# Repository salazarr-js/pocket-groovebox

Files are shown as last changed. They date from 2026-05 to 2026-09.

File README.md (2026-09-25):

# Pocket Groovebox

🎹 A modern DIY pocket groovebox. Just for fun.



## Status

Hardware checkpoint: peripherals verified on the ESP32-S3 (Phase 2 sketches done); keyboard CAD rebuild in progress ([hardware/3d/keyboard/octaves-plan.md](hardware/3d/keyboard/octaves-plan.md)). Next milestone: **build 1.0** — a one-octave (12-key) hand-wired keyboard integration build with printed caps + plate, no LEDs.

## Docs

- [docs/brief.md](docs/brief.md) — project brief (the why and what: vision, inspirations, principles)
- [docs/design.md](docs/design.md) — design & concept exploration (AI-generated prototype renders)
- [docs/hardware/README.md](docs/hardware/README.md) — hardware decisions (platform, components, power)
- [docs/hardware/wiring.md](docs/hardware/wiring.md) — how the modules connect to the ESP32-S3 (diagram + pin tables)
- [docs/plan.md](docs/plan.md) — build plan (checklist of steps by phase)
- [docs/architecture.md](docs/architecture.md) — firmware architecture (layer model, audio engine, open questions)
- [docs/development.md](docs/development.md) — dev environment setup (toolchain, libraries, build/flash)
- [docs/research/](docs/research/) — background research (synthesis, digital synths, drums, music theory)
- [docs/explorations/](docs/explorations/) — ADR-style decision records, mostly resolved (input method, key design, design system decided; keyboard CAD rebuild in progress)

## References

Inspirations behind the design are in the [brief](docs/brief.md#inspirations).

**Prior-art projects worth learning from:**
- Oskitone
  - https://github.com/oskitone/scout
  - https://youtu.be/TJ4WLL2fQbY
- https://github.com/wprudencio/esp32-synth

## Tools

- https://fritzing.org/
- https://wokwi.com/

**Live serial input** (char-by-char, raw terminal via `screen`): see [docs/development.md](docs/development.md).

### Skills
- https://github.com/ezrover/ESP32-AI-Agent-Skill
- https://github.com/adamlipecz/esp32-firmware-engineer-skill

## License

MIT — see [LICENSE](LICENSE).

## To process
- https://learn.adafruit.com/midi-keyset

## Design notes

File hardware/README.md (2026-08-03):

# hardware/

Design files for the Pocket Groovebox custom hardware. The *why* and decisions live in
[`docs/`](../docs/); this folder holds the *what* — organized by discipline.

```
hardware/
  3d/        OpenSCAD: shared layout + plate + caps + enclosure (.scad source)  ← production
```

## Toolchain

Decided in [docs/explorations/0004-cad-toolchain.md](../docs/explorations/0004-cad-toolchain.md):
**OpenSCAD** (mechanical + layout). FreeCAD is a fallback. KiCad was reserved for a custom PCB —
**dropped for V1**: the keyboard is hand-wired, no custom PCB (see [`3d/keyboard/octaves-plan.md`](3d/keyboard/octaves-plan.md)).
*(Ergogen was evaluated and dropped; v0's `octave-layout.scad` was deleted — the layout lives inside `plate.scad` per [`3d/keyboard/octaves-plan.md`](3d/keyboard/octaves-plan.md).)*

## 3d/

OpenSCAD parts. `.scad` is the versioned source. Design loop + collaborate live: **`/cad` skill**
(`.claude/skills/cad/`). **Design decisions + print results: [`3d/README.md`](3d/README.md).**

**Status: clean rebuild** — the v0 sources were print-validated (PLA/PETG, 0.2 & 0.4 mm nozzles, 3 print services) and then deleted on purpose; [`3d/keyboard/octaves-plan.md`](3d/keyboard/octaves-plan.md) holds the full rebuild plan, calibrated values and source snapshots. Target: **`key_cap.scad` + `plate.scad` + `assembly.scad`**, then incremental integration toward the two-shell enclosure (top shell absorbs the plate + display/speaker/encoders/joystick; bottom shell carries a perfboard main board).

## Key facts (see docs for detail)

- Switch: **Gateron KS-33 Low Profile 2.0 Silent Brown** — cutout **14.0 mm**, **stepped plate ~2.4 mm** (1.2 mm clip shelf), MX-cross stem.
- **Pitch is parametric** (`pitch = cap + gap`): cap 1u = **18 mm** + gap **0.8 mm** = **18.8 mm** currently (2026-08-01, on the 0.4 grid). Caps **OP-1 × HiChord** flat; switches hand-wired direct to **PCF8575** (no diodes, no custom PCB). Per-key **SK6812** RGB deferred (needs a PCB version).
- Full keyboard = **24 keys, C3–B4**. First build = **build 1.0**: one octave (**12 keys, C–B**), 1× PCF8575, hand-wired, **no LEDs** ([0005](../docs/explorations/0005-proto-keyboard-module.md)).
- This list is a summary — values live in [`3d/keyboard/octaves-plan.md`](3d/keyboard/octaves-plan.md) (single source).

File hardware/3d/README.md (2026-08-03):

# hardware/3d/ — OpenSCAD parts

3D-printable parts for the keyboard, **FDM print-validated** (PLA + PETG — see *Print-validated*
below), designed in OpenSCAD via the **`/cad`** loop
(`.claude/skills/cad/`). Reference dimensions and decisions:
[0002-key-design.md](../../docs/explorations/0002-key-design.md) and
[gateron-ks-33.md](../../docs/hardware/modules/gateron-ks-33.md) (the **Silent vernier table**
is the source of truth).

## Structure (settled 2026-08-03 — one folder per module family)

```
3d/
├── keyboard/            ← the keybed module (build 1.0: one octave)
│   ├── octaves-plan.md  ← THE rebuild plan — calibrated values, source snapshots (single source of values)
│   ├── key_cap.scad · plate.scad · assembly.scad
│   ├── wiring-plan.svg  ← soldering-view routing map (trails plate.scad — scad route data is the routing source of truth)
│   └── stl/             ← our exports (plate.stl, key_cap-*.stl)
├── vendor/              ← third-party reference meshes, committed — provenance + caveats in vendor/README.md
└── (future: deck/, enclosure/)
```

**The v0 sources were deleted on purpose (2026-07-31)** after the print validation — clean rebuild since. Everything needed is in [`keyboard/octaves-plan.md`](keyboard/octaves-plan.md) (plan, calibrated values, verbatim source snapshots) + the design notes below. File structure per plan §5: **`key_cap.scad` · `plate.scad` · `assembly.scad`** — three files, layout + cutout module live inside `plate.scad`.

Open a `.scad` in OpenSCAD (**Design → Automatic Reload and Preview**) and tune the Customizer
live; Claude edits + renders in parallel (`/cad` skill).

## Design decisions (this session, 2026-07)

### Plate (v0 `plate-octave.scad` / `switch-cutout.scad`, deleted — snapshot in [`octaves-plan.md`](keyboard/octaves-plan.md) §7)
- **Stepped cutout**, not a plain 14 mm hole: a **1.2 mm clip shelf at 14 mm** (the switch clips latch here), then the hole **widens to ~15.2 mm** below → the plate bottom sits **flush with the switch base**, so plate + switch both rest on the PCB. Plate total **~2.4 mm**. Rounded cutout corners (`hole_r`).
- **Screws:** **M2 countersunk hex-socket** (allen flat-head, DIN 7991) so they sit **flush** (a socket-cap counterbore is too deep for a 2.4 mm plate). Layout: **4 corners + 1 dead-centre** (in the gap between the natural and sharp rows). M2 **heat-set threaded inserts** go in the **enclosure**, not the plate (the plate is just a clearance hole).
- **Margins → 1.6 mm** (rev. 2026-08-01: = 2× cap_gap, 0.4 grid; plate corner `prad 3.2` = cap corner + margin, concentric): the plate will likely **merge into the enclosure** as the key container, so a big border isn't needed.
- **Pitch:** the **cap is fixed at 18 mm**; the gap sets the pitch (`pitch = cap + gap`). Current value: **gap 0.8 mm → pitch 18.8 mm** (decided 2026-08-01: 2×0.4 grid, backed by v0's print-validated 1.0 gap; the interim 0.5 was never printed side-by-side).

### Keycap (v0 `cap.scad`, deleted — snapshot in [`octaves-plan.md`](keyboard/octaves-plan.md) §7)
- **Design:** hollow shell (THT low-profile style, open bottom), rim → bevel → rounded top edge profile, central MX post with "+" cross bore. **Directional profile (2026-08-01):** per-side top insets, front (south) deepest — the slope reads as touch direction, OEM-style; bottom chamfers on skirt + post foot. **All parameter values** (walls, profile radii, insets, post/cross dims, `stem_clearance`, `mouth_flare`, sizes) live in [`octaves-plan.md`](keyboard/octaves-plan.md) §7 — the **single source of values**; don't duplicate them here.
- **Flat top / no dish.** A concave dish was tried three ways (spherical, rounded-rect clipped, ellipsoid "pill") and **removed** — it kept eating the rounded top edge and never matched the reference. **To revisit** with a different method.

### Toolchain proven
OpenSCAD driven headless by Claude via CLI (edit → `openscad --render` PNG → inspect → iterate),
plus FreeCAD headless to measure the official STEP. See [0004](../../docs/explorations/0004-cad-toolchain.md).

## ✅ Print-validated (2026-07)

The fit-test kit (2-space stepped plate + 1×2 and 1×1 caps) was printed and **passed** — switch clips firmly at the 1.2 mm shelf, cap cross-socket clips snug without cracking. The test parts were deleted after passing; the calibrated values live in the sources and are the spec:

- **Materials/processes:** PLA and PETG, FDM, **0.2 mm and 0.4 mm nozzles**, across **3 print services** — all fit.
- **Tolerances confirmed as-designed:** `kerf = 0` (plate cutout) and `stem_clearance = 0.18` (cap socket). Don't re-derive.
- **Finish:** **0.2 mm nozzle is the clear winner** — looks and feels better; 0.4 works but visibly rougher. Spec 0.2 for cosmetic/final parts; 0.4 acceptable for hidden/structural.
- **⚠️ Elephant foot is a real service-side risk:** one of the three services shipped parts with a squished first layer (their printer/slicer config — outside our control). **Design it out**: final parts get a small chamfer/lead-in on bottom edges (the cap's `mouth_flare` already does this; the plate cutouts and enclosure bottom edges should too).

## ⚠️ Open — design questions (see [plan.md](../../docs/plan.md))
- **Bottom-edge chamfers** against service-side elephant foot (see Print-validated) — ✅ **plate done (2026-08-02)**: outline chamfered on both faces (`edge_chamfer 0.3`) + top-rim chamfer on the switch cutouts (`hole_chamfer 0.15` — 45°, capped by the Silent's 14.5 flange seat on the 14.0 hole, so 0.3 is NOT possible there; 0 restores the exact print-validated geometry). Enclosure still pending.
- ✅ **Cross bore — resolved (2026-08-01, `key_cap.scad`):** the stem cross is asymmetric, but the wide arm is **1.23** (official drawing + vernier — the earlier 1.28 was a misread). The bore is now **per-arm** (1.23/1.10) with clearances **0.05/0.18** → **both slots 1.28**, which is bit-for-bit the print-validated v0 geometry (that's *why* it worked: same principle as injection MX caps — snug wide arm, loose thin arm). Equal slots ⇒ **no LED-north constraint needed**; it only appears if `stem_clearance_wide` is raised (the echo warns). Also adopted from the official cap spec: bore length **4.1** + **R0.3** inner-corner fillets.
- Revisit the **dish** (or keep flat).
- **Sharp offset** ("illusion" toward the true note) — not done.
- **Anti-tilt** for the tall 2u naturals — not addressed.
- ✅ **Pitch** — resolved for now: **18.8 mm** (cap 18 + gap 0.8, parametric, rev. 2026-08-01 — [`octaves-plan.md`](keyboard/octaves-plan.md) §7); revisit after build 1.0.
- ✅ **Sharps** — positions follow the layout snapshot in [`octaves-plan.md`](keyboard/octaves-plan.md) §7 (C#–D# at 1.5·pitch, F#–G#–A# at 1.25·pitch).

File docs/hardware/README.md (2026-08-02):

# Pocket Groovebox — Hardware

> I2S DAC (PCM5102), SPI display (ST7789), and PAM8403 amp are verified and wired. KY-023 joystick on hand, wiring defined. EC11 encoders not yet wired. Keyboard wiring is defined (24 keys via 2× PCF8575); V1 uses OP-1-style flat caps on switches, keycap + plate CAD in progress. Input method decision: **mechanical keys** ([0002-key-design.md](../explorations/0002-key-design.md)).
>
> **Build 1.0 scope** (first integration build): 1 octave C–B — 12 keys, 1× PCF8575, hand-wired, **no LEDs, no PCB**.

Hardware decisions for the device. For the *why* and *what*, see [brief.md](../brief.md); for build steps, see [plan.md](../plan.md).

> **DIY constraint.** These choices follow the brief's "Open, DIY hardware" principle: every part is an accessible, off-the-shelf maker module (breakout boards, common dev boards, standard cells) that anyone can source and rebuild — no custom silicon, no specialized fabrication. Enclosure and mechanical parts lean on home-friendly techniques (3D printing, laser-cut/CNC acrylic, repurposed toy instruments, robotics kits). When weighing a component, prefer the one that keeps the build reproducible.

## Hardware platform

**ESP32-S3** for both prototyping and V1. It has the RAM, CPU, BLE MIDI, and native USB to run standalone audio and DSP — and it's preferred over a Raspberry Pi (faster boot, lower power, smaller, cheaper) for a battery-powered instrument.

## Diagrams

> **Diagram convention.** Block/flow diagrams use **Mermaid** (rendered inline on GitHub) for design-time "what connects to what" — easy to edit as the design changes. Detailed, image-based wiring comes later for the build tutorial and per-module docs, drawn in **Fritzing** (breadboard view) and exported as **SVG** for crisp, properly licensed visuals.

### System overview

```mermaid
flowchart LR
    KEYS["24-key keyboard (2 octaves, C3–B4)"] --> MCU["ESP32-S3"]
    ENC["2× EC11 encoders"] --> MCU
    JOY["Joystick (analog)"] --> MCU
    MCU -->|SPI| LCD["ST7789 1.9in LCD"]
    MCU -->|I2S| DAC["PCM5102 DAC"]
    MCU -->|"GPIO18 → 74AHCT125"| LED["SK6812 MINI-E ×24 (deferred — needs PCB)"]
    DAC -->|line out| HP["Headphone jack"]
    DAC -->|line out| AMP["PAM8403 amp"]
    AMP --> SPK["Speaker"]
    BATT["18650 Li-Ion"] --> PWR["USB-C charge + boost + regulator"]
    PWR -->|3.3V| MCU
```

### Audio chain

```mermaid
flowchart LR
    MCU["ESP32-S3"] -->|I2S digital| DAC["PCM5102 I2S DAC"]
    DAC -->|analog line out| HP["Headphone jack"]
    DAC -->|analog line out| AMP["PAM8403 class-D amp"]
    AMP -->|BTL| SPK["Speaker"]
```

Note: both the PAM8403 and the MAX98357A are BTL (bridge-tied) speaker amps and cannot drive headphones directly — headphone/line out comes from the PCM5102.

## Component selection

| Area | Choice | Notes |
| --- | --- | --- |
| MCU | ESP32-S3 | More RAM/CPU, BLE MIDI, native USB |
| Keyboard | 24 keys (14 white + 10 black) — 2 octaves, C3–B4 | KS-33 Silent Brown low-profile switches (MX-cross stem), OP-1-style flat caps directly on switch (no lever — deferred), 18 mm cap + 0.8 mm gap → 18.8 mm pitch, front row ≈262 mm wide |
| Key I/O | 2× PCF8575 I2C expander (0x20 + 0x21) | 16 + 8 pins for 24 keys; shared INT on GPIO15 (open-drain wired-OR) |
| Key LEDs | SK6812 MINI-E ×24 | Per-key RGB, south-facing MX mount, 74AHCT125 level shifter on GPIO18. **Deferred — needs a PCB; build 1.0 has no LEDs** |
| Display | 1.9" ST7789 LCD, 170×320 SPI | BPM, presets, waveforms, menus |
| Controls | 2× EC11 rotary encoders + KY-023 joystick | Encoders on JTAG GPIO39–42 + GPIO16/17; joystick role TBD (pitch/expression/menu nav) — see [modules/ky023.md](modules/ky023.md) |
| Audio | PCM5102 I2S DAC + PAM8403 amp | DAC line out → headphone (PJ-320) + amp → speaker |
| Power | 1× 18650 Li-Ion (prototype) | Single charge/discharge module (IP5306-class): USB-C charge → boost → 5V → 3.3V, power-path, **KEY pin = power button**. Final cell *form* (cylindrical 18650 vs flat LiPo) TBD with enclosure layout |
| USB / data | Single combined USB-C 2.0 port | VBUS → charge module; D+/D− → ESP32 native USB (GPIO19/20) for serial + **USB-MIDI**; CC1/CC2 = 5.1 kΩ pulldowns |
| Storage | Internal flash | Built-in synth/sounds; microSD added later if needed |
| PCB | KiCad | ESP32-S3 + USB-C + charger + display + amp + encoders + key matrix |

Each module gets its own doc (pinout, photos, wiring, source) under [`modules/`](modules/). Pin-by-pin connections between modules are in [wiring.md](wiring.md).

## On hand vs sourcing

| Part | Status |
|---|---|
| ESP32-S3 dev board (Waveshare N32R16V) | ✅ On hand |
| PCM5102 DAC · PAM8403 amp (QA03) · ST7789 1.9" display | ✅ On hand |
| EC11 encoder ×2 · protoboard ×2 | ✅ On hand |
| KY-023 joystick | ✅ On hand · verified (sketch 12) |
| Dupont jumpers | ✅ On hand |
| KS-33 Silent Brown switches ×35 | 🛒 Ordered |
| SK6812 MINI-E ×50 | 🛒 Ordered |
| Springs 0.4×5×15mm ×20 | 🛒 Ordered (for the lever-key iteration — deferred) |
| 40mm full-range speaker 4Ω ×2 | 🛒 Ordered |
| PCF8575 ×5 (I2C expander) | 🛒 Ordered (1 on hand) |
| 74AHCT125 level shifter | ✅ On hand (unused until the LED/PCB version — deferred) |
| Charge/discharge module (IP5306-class, 5V/2A, power-path, KEY) | 🛒 Ordered |
| USB-C 2.0 breakout (6-pin, CC1/CC2 + 5.1 kΩ) | 🛒 Ordered |
| 18650 holder | 🛒 Ordered |
| EC11 knobs | 🛒 Ordered |
| Hookup wire 24 AWG solid — red/black 10 m, yellow 20 m | 🛒 Ordered |
| Enameled copper wire 0.4 mm 300 g (QA-1 solderable) | 🛒 Ordered |
| Perfboard | 🛒 Ordered |
| Wire stripper (10–30 AWG) | 🛒 Ordered |
| Headphone jack (PJ-320 3.5 mm stereo, ×several) | ❌ To buy |
| Power button (momentary, wired to KEY pin) | ❌ To buy |
| 18650 cell | ❌ To buy — local (AR) |
| Heat-shrink tubing kit | ❌ To buy |
| JST connectors (PH/XH) + crimp tool | ❌ To buy |
| DIP socket (for 74AHCT125) | ❌ To buy |
| Passives — see [Passives](#passives-single-source) table below | ❌ To buy — local (AR) |
| Tweezers · helping hands · desolder braid | ❌ To buy (nice-to-have) |

### Passives (single source)

This table is the **single source** for passive quantities and values — module docs reference it, not the other way around.

| Passive | Qty | Purpose |
| --- | --- | --- |
| 4.7 kΩ | 3 | I2C pull-ups: SDA, SCL, INT (PCF8575 bus) |
| 5.1 kΩ | 2 | USB-C CC1/CC2 pulldowns (sink role) |
| 100 µF electrolytic + 0.1 µF ceramic | 1 + 1 | PAM8403 amp 5 V decoupling (noise-floor reduction) |
| 330–500 Ω | 1 | LED chain — series resistor on DIN *(deferred — LED/PCB version)* |
| 100 nF ceramic | 24 | LED chain — decoupling, one per SK6812 *(deferred — LED/PCB version)* |
| 470–1000 µF electrolytic | 1 | LED chain — bulk cap at 5 V entry *(deferred — LED/PCB version)* |

## Power architecture

A **single USB-C port carries both charging and USB data**. At the connector the lines split: VBUS → the charge/discharge module; D+/D− → the ESP32-S3 native USB (serial + USB-MIDI); CC1/CC2 get 5.1 kΩ pulldowns (sink role).

```mermaid
flowchart LR
    USBC["USB-C 2.0 port (combined)"] -->|VBUS| MOD["Charge/discharge module (IP5306-class)"]
    USBC -->|"D+/D-"| MCU["ESP32-S3 native USB (GPIO19/20)"]
    BATT["18650 Li-Ion"] <--> MOD
    MOD -->|"5V + power-path"| RAIL["5V rail"]
    RAIL --> REG["ESP32 reg → 3.3V"]
    RAIL --> LED["SK6812 LEDs"]
    RAIL --> AMP["PAM8403 amp"]
    KEY["Power button"] -->|KEY pin| MOD
```

**Decisions:**
- **Single cell, not two:** simpler, safer, smaller, lower cost. Final cell *form* (cylindrical 18650 vs flat LiPo pouch) is decided with the enclosure interior layout — the module charges either (same Li-ion chemistry).
- **One charge/discharge module** (IP5306-class) does charging + 5V boost + power-path (use while charging) + battery protection in a single board — no separate charger/boost.
- **KEY pin = power button** (single press on / double press off) — no separate power switch.
- **VBUS routes only to the module**, never to the ESP32 5V pin — the ESP32 is always powered from the module's 5V output, so USB plug-in can't backfeed/fight the boost.
- **USB-MIDI requires the native USB** (GPIO19/20); the UART bridge can't do MIDI. The module's own USB-C is power-only and is **not** used for the combined port.
- Battery % via the module's 4-LED indicator, or the ESP32 ADC (voltage divider off the cell) for on-display readout.

## Tools

Bench tools and consumables needed to build and debug the device (not part of the device itself). To be filled in from actual purchases.

| Tool | Purpose | Status |
| --- | --- | --- |
| Soldering iron (65 W, temp-controlled) | Modules, headers, burning enamel off magnet wire | ✅ On hand |
| Multimeter (UNI-T UT89XD) | Continuity, voltage, current checks | ✅ On hand |
| Flush cutters | Trimming leads and wire | ✅ On hand |
| Wire stripper (10–30 AWG) | Stripping 24 AWG hookup wire | 🛒 Ordered |
| Solder + flux | Joints | — |
| Tweezers · helping hands · desolder braid | Fine-wire handling, soldering aid, rework | ❌ Nice-to-have |

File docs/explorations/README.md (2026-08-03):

# Explorations

Investigations and options being weighed **before** a decision is locked — research,
alternatives, tradeoffs. Each file is lightweight (ADR-style) with a `Status:` line
(`exploring → leaning toward X → decided`). One numbered file per topic.

This is **not** for bugs (see [../issues/](../issues/)) nor settled reference material
(see [../synthesis.md](../research/synthesis.md), [../music-theory.md](../research/music-theory.md)).

| # | Topic | Status | File |
| --- | --- | --- | --- |
| 0001 | Input method (mechanical keys vs capacitive touch vs ribbon; Solar 42) | decided — mechanical keys + PCF8575 | [0001-input-method.md](0001-input-method.md) |
| 0002 | Key design (switch, mechanism, layout, look & feel) | decided — geometry superseded by [`octaves-plan.md`](../../hardware/3d/keyboard/octaves-plan.md) | [0002-key-design.md](0002-key-design.md) |
| 0003 | Design system (4 mm measurement grid) | decided — 4 mm grid; keyboard is an off-grid exception | [0003-design-system.md](0003-design-system.md) |
| 0004 | CAD & fabrication toolchain | decided, revised — KiCad dropped (no custom PCB) | [0004-cad-toolchain.md](0004-cad-toolchain.md) |
| 0005 | Proto keyboard module (one octave) | superseded in part → build 1.0 | [0005-proto-keyboard-module.md](0005-proto-keyboard-module.md) |

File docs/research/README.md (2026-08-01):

# Theory

Stable domain-knowledge reference — *how synthesis and music work* in general. Not specific to
this device's product design (that's [../design.md](../design.md)) nor its hardware
([../hardware/](../hardware/)).

| Topic | File |
| --- | --- |
| **Synthesis** — oscillators/waveforms, ADSR, filter, polyphony, the subtractive voice chain | [synthesis.md](synthesis.md) |
| **Music theory** — notes, intervals, scales, chords, rhythm/timing | [music-theory.md](music-theory.md) |
| **Drum synthesis** — technique reference (V1 drums are synthesized — see `architecture.md`): lessons learned, TR-808/909/606 breakdown, machines to research | [drums.md](drums.md) |
| **Digital synthesizers** — synthesis paradigms (subtractive/wavetable/FM/PD), Serum 2, DigitsVst, HiChord product analysis, learning resources | [digital-synths.md](digital-synths.md) |

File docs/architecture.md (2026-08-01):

# Pocket Groovebox — Firmware Architecture

Design decisions for the Phase 3 firmware. Written after the Phase 2 exploration sketches
to capture what we learned and define the right foundation before writing production code.

> **Status:** planning — **blocked on synthesis research.** Nothing here is implemented yet.
> Decisions marked ✅ are settled; those marked ❓ are open questions.
>
> **One research track must complete before this architecture is finalized:**
> - **Synthesis system** — which engines (subtractive, FM, wavetable, phase distortion?), voice budget, modulation system, patch model. Current audio engine design is a starting point, not a final answer. Research may change the voice model, layer count, or CPU budget assumptions.
>
> **Resolved:** input method — mechanical keys via 2× PCF8575 I2C expanders. See `docs/explorations/0001-input-method.md` (method) and `docs/explorations/0002-key-design.md` (key design).
>
> Do not begin Phase 3 implementation until the synthesis research is resolved.

---

## Why a new architecture

The exploration sketches (01–16) were written with Arduino IDE and no shared code. They
taught us the hardware and the problem space well. But they don't scale:

- Audio engine, sequencer, and protocol are tangled together in each sketch
- No shared types — `Key`, `DrumVoice`, `Layer` redefined per file
- Arduino auto-prototype injection breaks on user-defined structs (hit this with sketch 11)
- No way to unit-test audio math without the hardware
- Adding a feature (e.g. a filter to the oscillator) requires touching the inner loop in every sketch

Phase 3 firmware is written from scratch with PlatformIO and a clear layer separation.

---

## Layer model

```
┌─────────────────────────────────────────────────────┐
│  UI layer — display, encoders, key matrix           │  reads input, draws state
├─────────────────────────────────────────────────────┤
│  App layer — sequencer, modes, patch management     │  orchestrates voices + UI
├─────────────────────────────────────────────────────┤
│  Audio engine — voice pool, mixer, effects          │  runs in the I2S callback
├─────────────────────────────────────────────────────┤
│  HAL — I2S, SPI, GPIO, NVS, timers                 │  hardware abstraction
└─────────────────────────────────────────────────────┘
```

Each layer talks only to the layer below it. The UI never touches the I2S buffer; the
audio engine never reads a GPIO pin.

---

## Toolchain ✅

**PlatformIO** replaces Arduino IDE.

- `platformio.ini` at repo root defines the ESP32-S3 target, framework (Arduino or IDF),
  and shared library paths
- `firmware/` holds PlatformIO projects (one per major feature or the combined V1 firmware)
- `lib/` holds shared C++ modules (audio engine, etc.) — imported by all projects
- VS Code + PlatformIO extension is the primary IDE

Reasons: proper dependency management, project-scoped builds, no auto-prototype injection,
unit testing possible via `test/` directory, multi-environment builds (debug / release).

---

## Audio engine

### Voice model ✅

A **voice** is the unit of sound. Each voice has:

```
Oscillator → Filter (SVF) → VCA → out
                ↑               ↑
          [filter env]     [amp env]        ← both are full ADSR
```

This is the same subtractive model described in [research/synthesis.md](research/synthesis.md),
but now the envelope and oscillator are concrete, reusable C++ types.

### Oscillator ✅

```cpp
struct Oscillator {
  float phase = 0;
  float inc   = 0;        // 2π × freq / SAMPLE_RATE
  WaveShape shape = SINE; // SINE, SAW, SQUARE, TRIANGLE

  float next();           // returns next sample in -1..1
  void  setFreq(float hz);
  void  setShape(WaveShape s);
};
```

`next()` switches on `shape`; wavetable lookup replaces the `sinf()` call once we measure
CPU headroom. Anti-aliasing (PolyBLEP) added if aliasing is audible on high notes.

### Envelope — ADSR ✅

Exponential decay is the critical improvement over the exploration sketches.
Linear `env -= rate` sounds artificial. Exponential `env *= coeff` matches how all
physical systems decay (strings, drums, room reverb).

```cpp
struct Envelope {
  float attackSecs  = 0.005f;
  float decaySecs   = 0.1f;
  float sustainLevel= 0.7f;
  float releaseSecs = 0.05f;

  void noteOn();
  void noteOff();
  float next();   // call once per sample; returns 0..1
};
```

`next()` runs the state machine: IDLE → ATTACK → DECAY → SUSTAIN → RELEASE → IDLE.
Attack is linear (sounds natural for the rising edge). Decay and release are exponential:
`level *= decayCoeff` where `decayCoeff = expf(-1.0f / (SAMPLE_RATE × decaySecs))`.

### Filter — State-Variable Filter (SVF) ✅

The SVF gives low-pass, high-pass, and band-pass simultaneously from one struct, is
numerically stable, and is easy to modulate (cutoff and resonance change per sample with
no stability risk). It's the right choice for both synth voices and drum noise shaping.

```cpp
struct SVF {
  float cutoff    = 1000.0f;  // Hz
  float resonance = 0.5f;     // 0..1 (0 = none, approach 1 for self-oscillation)

  void  setParams(float cutHz, float q);
  float nextLP(float in);   // low-pass output
  float nextHP(float in);   // high-pass output
  float nextBP(float in);   // band-pass output
  // or: struct Out { float lp, hp, bp; }; Out next(float in);
};
```

The Chamberlin SVF topology is the standard reference. One multiply per sample per mode.

### Voice pool ✅

```cpp
constexpr int MAX_VOICES = 8;

struct Voice {
  Oscillator osc;
  SVF        filter;
  Envelope   ampEnv;
  Envelope   filterEnv;  // optional: sweeps filter cutoff
  bool       active = false;
  int        noteKey = -1;
};

Voice voicePool[MAX_VOICES];

Voice* allocate(int key);   // steal oldest if all busy
void   release(int key);
```

Voice stealing policy: steal the voice with the lowest amplitude (quietest = least audible
interruption). Fall back to oldest-active if all are at similar levels.

> ⚠ **Open tension:** `MAX_VOICES = 8` may be too low. The HiChord analysis in [research/digital-synths.md](research/digital-synths.md) suggests 12 simultaneous oscillators as the real voice budget for polyphonic chord play — up to 18 note-slots (6 chord voices × 3-note triads). To be resolved in the synthesis research before this constant is locked.

### Mixer ✅

Sum all active voices, scale by `1.0f / MAX_VOICES` to prevent clipping when all fire
at once. A soft limiter (tanh or cubic saturation) on the final output before the int16
conversion prevents hard clipping while adding a small amount of pleasant warmth.

```cpp
float mix = 0;
for (auto &v : voicePool) mix += v.next();
mix *= 1.0f / MAX_VOICES;
mix = tanhf(mix * drive) / tanhf(drive);  // soft limiter; drive ≈ 1.5–2.0
int16_t out = (int16_t)(mix * 32767.0f);
```

The **speaker output path** additionally gets a high-pass filter at **~150–200 Hz**: the small speaker barely reproduces anything below that, and cutting the sub-bass frees headroom and reduces distortion through the PAM8403. (Finding migrated from [issues/01-audio-issues.md](issues/01-audio-issues.md), where a 2-pole high-pass was prototyped and deferred to the production DSP chain.)

### Audio callback ✅

The I2S write happens in a tight loop in `loop()` (same as exploration sketches) or in a
FreeRTOS task pinned to core 0. The audio engine is the only thing that runs there.
All state changes from the UI/sequencer come through a lock-free ring buffer or atomic
flags — no mutexes in the audio path.

---

## Sequencer

### Data model ❓ (open question)

Two options:

**Option A — Unified timeline (piano roll model)**
Every event is a `{step, lane, noteOrDrum, velocity}` record. Drum hits and pitched notes
live on the same 32-step grid. Cleaner data model; harder to display.

**Option B — Separate pitched + drum grids (TR-style)**
Pitched voices: N-step pattern per layer (like sketch 10-audio-looper).
Drum voices: 1-bit per drum per step (like sketch 11, the removed drum machine).
Simpler to display and edit on a small screen; two separate data structures.

Decision: resolve when the display layout is designed — the UI constraint drives the
data model choice more than the audio engine does.

### Step resolution ✅

16th notes at the default BPM. Optionally 32nd notes (double resolution). BPM range:
20–300. `stepMs = 60000 / BPM / 4` (same formula as exploration sketches, confirmed stable).

### Live recording ✅

While playing + recording, incoming note-on events are OR'd into the current step.
This matches the looper sketch behavior and feels natural for performance recording.

---

## Drum voices ✅

**Decision: synthesized drums for V1, with the sampler path kept open for V2.**

Drum voices use the same audio engine primitives as synth voices (SVF + exponential ADSR +
oscillator). Each drum type is a fixed recipe:

```
Kick  = Oscillator(SINE) + exp_pitch_env (fast drop) + SVF(LP) + exp_amp_env
Snare = 2× Oscillator(SINE, detuned) + noise source + SVF(BP) + exp_amp_env
Hat   = 6× Oscillator(SQUARE, inharmonic) + SVF(HP) + very short exp_amp_env
```

Reference implementations: Mutable Instruments Peaks (open source), the LZXIV and
MI Elements source for noise generation.

**Why synthesized first:**
- No flash storage overhead — drum recipes are just parameter sets
- Fully configurable: tune a kick's pitch, decay, punch with the same envelope/filter
  params used everywhere else
- Reuses the voice pool without a separate sample-playback path
- Hardware constraint: exponential envelopes are already required (learned from sketch 11)

**Sampler upgrade path (V2):**
The voice pool interface is designed so a `SampleVoice` can slot in alongside `SynthVoice`
without touching the mixer or sequencer. When the sampler is added:

```cpp
// V1: all voices are SynthVoice
Voice pool[MAX_VOICES];  // SynthVoice = Oscillator + SVF + ADSR

// V2: voice pool becomes polymorphic
struct IVoice { virtual float next() = 0; virtual void noteOn(int key) = 0; ... };
SynthVoice  : IVoice  // current drum + synth voices
SampleVoice : IVoice  // PCM16 array reader, added in V2
```

PCM samples (if added) would be baked as C arrays in flash via a `wav2c` script and played
back at the original sample rate. The mixer treats them identically to synth voices.

---

## UI layer

### Inputs

- ✅ Keyboard: **24 keys, C3–B4** (14 naturals + 10 sharps) via 2× PCF8575 I2C expanders (chip #1 = C3–D#4, 16 keys; chip #2 = E4–B4, 8 keys + 8 spares); debounced via timer or state comparison each frame
- Rotary encoders (EC11 × N): interrupt-driven edge count + button debounce
- ❓ How many encoders? TBD — depends on final control layout

### Display ✅

ST7789 over SPI via Arduino_GFX. Double-buffered where possible. UI redraws only changed
regions (dirty-rect tracking) to avoid blocking the audio loop.

Display update runs in `loop()` after the audio write, or in a FreeRTOS task on core 1
(audio on core 0, UI on core 1). The I2S callback is the timing constraint — display
must not block it.

### State communication between UI and audio ✅

The audio engine never blocks on UI. Communication is one-directional:
- UI → Audio: atomic flags or a small lock-free ring buffer (`NoteEvent` structs)
- Audio → UI: shared atomic state (current step, active notes bitmask, CPU load counter)

No mutexes in the audio path.

---

## Persistence

NVS (Non-Volatile Storage) via the Arduino `Preferences` library or ESP-IDF NVS API.

- **Settings** (BPM, master volume, active mode) — stored on change
- **Patterns** — stored on user request (hold a button) or on power-off if practical
- **Presets** — named patches for the synth voice parameters

NVS survives power cycles and firmware updates (unless the partition table changes).

---

## Project structure (PlatformIO)

The structure below matches `platformio.ini` as it exists today: a single environment `waveshare-esp32-s3-r32n16`, with `src_dir`, `lib_dir`, `test_dir`, and `include_dir` all under `firmware/`.

```
pocket-groovebox/
├── platformio.ini          ← single env: waveshare-esp32-s3-r32n16 (32 MB flash / 16 MB PSRAM)
├── firmware/
│   ├── src/                ← main firmware source (currently a board validation sketch)
│   ├── lib/                ← shared modules: audio, sequencer, ui, hal
│   ├── include/            ← shared headers
│   └── test/               ← unit tests: test_envelope, test_oscillator, test_svf
├── sketches/               ← Phase 2 exploration .ino sketches (reference only)
├── app/                    ← web bridges (keyboard-bridge, looper-bridge)
├── hardware/               ← OpenSCAD parts + plans (no custom PCB)
└── docs/
```

`firmware/lib/audio` is the most critical — it runs at 44.1 kHz and must be tested independently
of the hardware. PlatformIO's native unit test environment (runs on the host machine, not
the ESP32) makes this possible.

---

## Open questions (resolve in order)

1. ~~**Drum approach**~~ ✅ Synthesized for V1; polymorphic `IVoice` interface keeps sampler path open for V2.
2. **Sequencer data model** — unified timeline vs separate grids? Resolve when display layout is designed.
3. **Number of encoders** — physical control layout TBD.
4. **FreeRTOS or single-core loop?** — single-core loop works if the audio block stays < ~3 ms. Measure first.
5. **Wavetable vs sinf()** — profile sinf() with 8 voices. If it's a bottleneck, switch to a 1024-entry wavetable lookup.

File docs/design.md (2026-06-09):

# Pocket Groovebox — Design & Concept Exploration

Visual exploration of what the device could look and feel like. These are **concept
renders, not specs** — they explore form factor, layout, and personality. The product
direction lives in [brief.md](brief.md#product-concept); component reality lives in
[hardware.md](hardware/README.md).

## Concepts

### 01 — Two-level handheld layout

Elevated control section (encoders + display) above a lower keyboard zone. Steam Deck–style
two-hand grip. Cream/gray body with orange accents. Speaker grille bottom-right, joystick
bottom-left.

| nano banana (Gemini) | ChatGPT |
| --- | --- |
|  |  |

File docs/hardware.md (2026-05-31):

# Pocket Groovebox — Hardware

> 🚧 **Draft — not final.** These component and architecture choices are provisional and still need validation through bench tests. Expect changes (especially the audio path). Treat nothing here as locked until verified on the board.

Hardware decisions for the device. For the *why* and *what*, see [brief.md](brief.md); for build steps, see [plan.md](plan.md). Term definitions are in [glossary.md](glossary.md).

> **DIY constraint.** These choices follow the brief's "Open, DIY hardware" principle: every part is an accessible, off-the-shelf maker module (breakout boards, common dev boards, standard cells) that anyone can source and rebuild — no custom silicon, no specialized fabrication. Enclosure and mechanical parts lean on home-friendly techniques (3D printing, laser-cut/CNC acrylic, repurposed toy instruments, robotics kits). When weighing a component, prefer the one that keeps the build reproducible.

## Hardware platform

**ESP32-S3** for both prototyping and V1. It has the RAM, CPU, BLE MIDI, and native USB to run standalone audio and DSP — and it's preferred over a Raspberry Pi (faster boot, lower power, smaller, cheaper) for a battery-powered instrument.

## Diagrams

> **Diagram convention.** Block/flow diagrams use **Mermaid** (rendered inline on GitHub) for design-time "what connects to what" — easy to edit as the design changes. Detailed, image-based wiring comes later for the build tutorial and per-module docs, drawn in **Fritzing** (breadboard view) and exported as **SVG** for crisp, properly licensed visuals.

### System overview

```mermaid
flowchart LR
    KEYS["13-key keyboard"] --> MCU["ESP32-S3"]
    ENC["2x EC11 encoders"] --> MCU
    MCU -->|SPI| LCD["ST7789 1.9in LCD"]
    MCU -->|I2S| DAC["PCM5102 DAC"]
    DAC -->|line out| HP["Headphone jack"]
    DAC -->|line out| AMP["PAM8403 amp"]
    AMP --> SPK["Speaker"]
    BATT["18650 Li-Ion"] --> PWR["USB-C charge + boost + regulator"]
    PWR -->|3.3V| MCU
```

### Audio chain

```mermaid
flowchart LR
    MCU["ESP32-S3"] -->|I2S digital| DAC["PCM5102 I2S DAC"]
    DAC -->|analog line out| HP["Headphone jack"]
    DAC -->|analog line out| AMP["PAM8403 class-D amp"]
    AMP -->|BTL| SPK["Speaker"]
```

Note: both the PAM8403 and the MAX98357A are BTL (bridge-tied) speaker amps and cannot drive headphones directly — headphone/line out comes from the PCM5102.

## Component selection

| Area | Choice | Notes |
| --- | --- | --- |
| MCU | ESP32-S3 | More RAM/CPU, BLE MIDI, native USB |
| Keyboard | 13 keys (8 white + 5 black) | One octave, nanoKEY2-style mini keys |
| Display | 1.9" ST7789 LCD, 170×320 SPI | BPM, presets, waveforms, menus |
| Controls | 2× EC11 rotary encoders | Volume, navigation, BPM, sound/params |
| Audio | PCM5102 I2S DAC + PAM8403 amp | DAC line out → headphone; amp → speaker. MAX98357A is a compact mono alternative. |
| Power | 1× 18650 Li-Ion | USB-C charging → boost → 5V → 3.3V |
| Storage | Internal flash | Built-in synth/sounds; microSD added later if needed |
| PCB | KiCad | ESP32-S3 + USB-C + charger + display + amp + encoders + key matrix |

Most of these parts are already on hand. Each module gets its own doc (pinout, photos, wiring, source) under [`modules/`](modules/) — copy [`modules/module-template.md`](modules/module-template.md) per part as you bench-test it.

## Power architecture

```mermaid
flowchart LR
    BATT["18650 Li-Ion"] --> CHG["USB-C charging module"]
    CHG --> BOOST["Boost converter"]
    BOOST -->|5V| REG["ESP32 regulator"]
    REG -->|3.3V| SYS["ESP32-S3 + peripherals"]
```

Single cell, not two: simpler, safer, smaller, and lower cost.

## Tools

Bench tools and consumables needed to build and debug the device (not part of the device itself). To be filled in from actual purchases.

| Tool | Purpose | On hand |
| --- | --- | --- |
| Soldering iron | Assembling modules and headers | — |
| Solder + flux | Joints | — |
| Multimeter | Continuity, voltage, current checks | — |
| _(send your list)_ | | |

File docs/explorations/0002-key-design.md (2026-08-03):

# 0002 — Key design

**Status:** decided (OP-1-style flat caps, direct on switch)  ·  (`open → exploring → decided → revised`)

> **Revision (2026-07) — OP-1 pivot (V1).** For the **first iteration**, the lever-bridge +
> piano-key mechanism is **deferred** in favour of the OP-1 approach: **flat rectangular keycaps
> mounted directly on the switch**, no lever, no sculpted piano-key structure. Reasons: far
> simpler mechanically, no springs or pivot rod, and it's cheap to 3D-print and **easy to
> re-print a single bad part** — the priority for the first physical instance (fabrication is
> outsourced to a print service). The note layout stays a **flattened 2-octave piano** (naturals
> row + sharps offset in a back row) so it still plays like an instrument. The lever design is
> **kept open below as a candidate for a later iteration** — not rejected, just parked to keep V1
> simple. Switch choice and the 2-octave range are unchanged. *(Pitch has since moved to parametric — cap 18 mm + gap 0.5 mm = 18.5 mm; see `hardware/3d/keyboard/octaves-plan.md` §7.)*

Decisions taken:
- ✅ Switch: **Gateron KS-33 Low Profile 2.0 Silent Brown** — full specs + mechanical drawing in [`../hardware/modules/gateron-ks-33.md`](../hardware/modules/gateron-ks-33.md)
- ✅ Mechanism (**V1**): **flat rectangular cap directly on the switch** (OP-1 style; no lever, no spring, no pivot rod). Lever bridge deferred to a later iteration — see bottom.
- ✅ Cap mounting: **thin low-profile cap with a guide rib that inserts into a plate slot** (G915-style — the guide lives in the cap, not the plate walls). The rib reuses the plate's **stabilizer cutout** as its guide slot, so **no MX stabilizer hardware** is needed. Stem socket = MX cross (4.00 / 1.10 / 1.23). *(The "skirt wrapping the switch body" variant and the plate-well "floating cap" were considered and dropped.)*
- ✅ Layout: **flattened 2-octave piano** = **24 keys** — 14 naturals (C3–B4, 1u × 2u tall) + 10 sharps (back row: C#/D#/F#/A# = 1.5u wide, G# = 1u). From the user's KLE; encoded in `hardware/3d/octave-layout.scad` *(deleted with v0 — the layout now lives inside `plate.scad` per [`octaves-plan.md`](../../hardware/3d/keyboard/octaves-plan.md))*. *(No top C5.)*
- ✅ Pitch: **parametric** — `pitch = cap + gap`; cap fixed at 1u = 18 mm, gap currently 0.5 mm → **18.5 mm pitch** (24-key front row ≈ 259 mm; values per [`octaves-plan.md`](../../hardware/3d/keyboard/octaves-plan.md) §7 — see also [0003-design-system.md](0003-design-system.md))
- ✅ Plate: **3D-printed**, 1.2 mm low-profile cutout (14 mm), outsourced to a print service
- ✅ Look & feel: **OP-1 × HiChord** (primary aesthetic references) — refined minimalism, flat rounded-rectangle caps, muted base palette + per-key RGB color accents; premium tactile, not toy-like
- ✅ Cutout confirmed by **vernier**: switch housing 13.8 mm / relaxed clips 14.5 mm → plate cutout **14.0 mm** (housing passes, clips grip). Two tilt axes to guide: naturals (2u tall) tilt fore-aft; wide sharps (1.5u) tilt sideways.
- ✅ Toolchain: layout + plate + caps in **OpenSCAD** — see [0004-cad-toolchain.md](0004-cad-toolchain.md). *(KiCad since dropped for V1 — no custom PCB, keyboard hand-wired.)*
- 🚧 First build: **build 1.0** — a one-octave module (12 keys, C–B, hand-wired, no LEDs) before the full 24 — see [0005-proto-keyboard-module.md](0005-proto-keyboard-module.md).

## Context

The keyboard uses **Gateron KS-33 Low Profile 2.0 Silent Brown** switches (15×15 mm body,
MX-style cross stem). The goal is a keyboard that looks and plays like an instrument — not a
computer keyboard — while staying simple enough to 3D-print and iterate cheaply.

## Decision: switch — KS-33 Silent Brown

**Decided: Gateron KS-33 Low Profile 2.0 Silent Brown.** Key values: silent tactile, **55 ± 15 gf** operating force, **15 × 15 mm** body with MX-cross stem. All other dimensions (travel, stem cotas, plate cutout/thickness, the dimensional drawing) live in the [module doc](../hardware/modules/gateron-ks-33.md) — the single source for switch specs.

Chosen for: silent + pre-lubed out of the box, low height (~12 mm body saves ~6 mm vs MX),
cheaper than silent tactile MX, and an MX-cross stem that keeps keycap options open.

## Decision: mechanism — flat cap directly on switch (OP-1 style)

No lever, no spring, no pivot. **Each key = one switch + one 3D-printed rectangular cap.**
The finger presses the cap, the cap presses the switch stem, 3 mm of travel. This trades the
piano-like deep travel of the lever design for radical simplicity and easy iteration.

### Cap mounting — two routes

- **Floating cap, guided by the plate (primary).** The rectangular cap sits in a well in the
  plate and pushes the stem via a **nub** underneath; it does *not* clip the stem. Most forgiving
  for outsourced FDM, and a bad cap is re-printed on its own without depending on the tiny stem
  fit. Recommended for the first instance.
- **Stem-mounted cap (plan B).** The cap has a cross socket that clips onto the stem. Cleaner
  look, feasible now that we have exact stem cotas (model the socket to 4.00 / 1.10 / 1.23, not
  generic MX 1.17/1.27). Better in resin.

### Terminology

See the [module-doc glossary](../hardware/modules/gateron-ks-33.md#anatomy--glossary) for
cap / nub / stem / pins.

## Decision: layout — flattened 2-octave piano

**Range: C3–B4 = 24 keys** (14 naturals + 10 sharps, no top C5). Two rows of flat rectangular caps: naturals in the front row, sharps offset in a back row (with the usual gaps at E–F and B–C), like the OP-1.

```
  ▢ ▢     ▢ ▢ ▢     ▢ ▢     ▢ ▢ ▢     ← sharps (back row, 10)
▢ ▢ ▢ ▢ ▢ ▢ ▢ ▢ ▢ ▢ ▢ ▢ ▢ ▢          ← naturals (front row, 14)
C D E F G A B C D E F G A B
```

### Switch grid (mm, from the left-most natural center = x 0)

> **Superseded** — this grid assumed 25 keys at a fixed 18 mm pitch. Current geometry (24 keys, parametric pitch 18.5 mm, unit-based layout) lives in [`hardware/3d/keyboard/octaves-plan.md`](../../hardware/3d/keyboard/octaves-plan.md) §7. Kept for the reasoning.

**Naturals (front row, y = 0):** 15 switches at `x = n × 18`, n = 0…14
→ 0, 18, 36, 54, 72, 90, 108, 126, 144, 162, 180, 198, 216, 234, 252
(notes C3 D3 E3 F3 G3 A3 B3 C4 D4 E4 F4 G4 A4 B4 C5).

**Sharps (back row, y = +row-spacing):** 10 switches, centered on the boundary between the two
naturals they sit between → `x = (i + 0.5) × 18`:

| Note | x (mm) | Note | x (mm) |
|---|---|---|---|
| C#3 | 9 | C#4 | 135 |
| D#3 | 27 | D#4 | 153 |
| F#3 | 63 | F#4 | 189 |
| G#3 | 81 | G#4 | 207 |
| A#3 | 99 | A#4 | 225 |

(No sharp at x 45 / 117 / 234 — the E–F and B–C gaps.)

### Cap & row dimensions (starting points — tunable)

> **Superseded** — current cap geometry (1u = 18 mm units, print-validated values) lives in [`hardware/3d/keyboard/octaves-plan.md`](../../hardware/3d/keyboard/octaves-plan.md) §7. Kept for the reasoning.

| Dimension | Value | Notes |
|---|---|---|
| Natural cap | 16 × 20 mm (W×D) | 16 = pitch − 2 mm gap; depth is free now (no lever) |
| Sharp cap | 10 × 16 mm | width per design system; free-standing rectangle, can widen |
| Row spacing (natural↔sharp switch centers) | ~17 mm | **hard floor ≈16 mm**: 15 mm bodies interleave in X, so the rows must clear in Y |
| Keyboard span (width) | 270 mm | 15 × 18; unchanged |
| Keyboard depth | **~35 mm** | down from ~72 mm+ with levers — see consequences |

> **Body-collision constraint:** a sharp at x 9 sits between naturals at x 0 and x 18; their
> 15 mm bodies overlap in X, so the sharp row must be offset in Y by at least one body depth
> (~16 mm). This sets the row-spacing floor, not aesthetics.

## Look & feel — OP-1 × HiChord (design language)

The keys target the aesthetic of two Primary references in [brief.md](../brief.md):

- **OP-1** — flat rectangular caps with softly rounded corners, deliberate color accents, personality without clutter.
- **HiChord** — premium CNC-aluminium / anodised minimalism, tight tolerances, colored buttons used for *visual hierarchy* (function vs play keys); a "serious tool, pocket-sized" — not a toy.

Shared target: **refined minimalism with intentional color**, a quiet premium tactile press, and uniform tight gaps that read as "considered."

| Aspect | Direction |
|---|---|
| Cap form | Flat rectangle, softly rounded corners (r ~1–2 mm), uniform tight gaps |
| Base palette | Muted / anodised-like (black, cream, warm gray) — pick one shell colorway |
| Color accents | Per-key **SK6812 RGB** carries the color — HiChord-style hierarchy (active note, chord tones, mode) + OP-1 pops. It's *lit*, not painted, so it reconfigures per mode |
| Feel | KS-33 **silent tactile** already matches the quiet, quality press both aim for |
| Finish (our reality) | We 3D-print, not CNC aluminium → prefer **resin caps** for a smoother surface, and hold tight, consistent tolerances so the printed grid still reads premium |

Note: HiChord is a *chord* instrument — we borrow its **look and feel**, not its 7-button chord layout. Our layout stays the flattened 2-octave piano; chord/scale behaviour can be layered via modes + the RGB without changing the physical keys.

## Consequences

- **Keyboard depth drops from ~72 mm to ~35 mm.** Removing the lever frees ~35–40 mm of device
  depth. This should be reflected in [0003-design-system.md](0003-design-system.md) and the
  enclosure layout — the 160 mm frame height now has significant slack, or the device can shrink.
- **No PCB — hand-wired**: 24 switches wired directly to 2× PCF8575 (no diodes, common GND — see [module doc](../hardware/modules/gateron-ks-33.md#wiring-to-the-keyboard-i2c-expanders)). The plate carries the switches; wiring routes to the expander modules.
- **3D-print files needed**: (1) natural cap, (2) sharp cap, (3) plate with 14 mm cutouts +
  cap wells at the grid above. Print a **single-key test** first to validate cutout clip, cap
  fit, and feel before committing to all 24.
- **No springs, no pivot rod** — the compression springs and steel rod from the lever design are
  dropped from the BOM.
- Update `docs/hardware/enclosure-layout.svg`: replace the sculpted piano keys with the two-row
  flat-cap grid and reclaim the freed depth.

---

## CAD — plate & keycap (first pass, 2026-07)

> **Superseded** — the v0 sources described here were print-validated and then deleted on purpose; current geometry lives in [`hardware/3d/keyboard/octaves-plan.md`](../../hardware/3d/keyboard/octaves-plan.md) §7. Kept for the reasoning.

First OpenSCAD pass — files + full parametric detail in [`hardware/3d/README.md`](../../hardware/3d/README.md):

- **Plate:** **stepped cutout** — 1.2 mm clip shelf at 14 mm, widened to ~15.2 mm below, so the ~2.4 mm plate sits **flush with the switch base** and both rest on the PCB. **M2 countersunk (allen flat-head)** screws, 4 corners + 1 dead-centre; **heat-set inserts in the enclosure**. Margins 1 mm (the plate is expected to merge into the enclosure as the key container).
- **Keycap:** **hollow shell** (THT low-profile) — straight base rim → bevel → **rounded top edge**; central cylindrical **post with a "+" cross bore**. **Flat top** (a dish was tried three ways and removed — to revisit).
- **Pitch:** the cap is fixed at **18 mm**; the gap sets the pitch (`pitch = cap + gap`). Decided 2026-07-31: gap 0.5. **Rev. 2026-08-01: gap 0.8 mm → 18.8 mm pitch** (2×0.4 design grid; v0's 1.0 gap was print-validated, 0.5 never was — parametric, revisit after build 1.0).
- **Assembly:** `assembly-octave.scad` *(deleted with v0 — rebuild target is `assembly.scad` per octaves-plan)* rendered the octave with real caps to judge the whole together.

⚠️ **Before any print:** deep-check every measurement (cutout, stepped shelf, plate thickness, cap dims, **stem socket**) against other keycap/plate models — tracked in [plan.md](../plan.md).

## Deferred to a future iteration — lever bridge + spring

> **Open, not rejected.** This mechanism is parked for a later iteration; V1 keeps it simple with
> flat caps (see top). It's a strong candidate for a V2 that wants real piano feel: it amplifies
> the 3 mm switch travel to ~7–8 mm at the finger via a lever, with a compression spring tuning
> force independently — at the cost of springs, a pivot rod, deep 72 mm keys, and per-key parts
> that are fiddly to 3D-print. Revisit once the flat-cap V1 is validated.

- **Lever bridge**: keycap on a lever pivoting at the back; `finger_travel = switch_travel × (b/a)`.
  Target was 7–8 mm travel at 40–50 gf, with switch at ~20 mm from a ~55 mm finger point (ratio ~2.75×).
- **Spring compensation**: a compression spring at distance `c` restored force after the lever
  divided it down: `finger_force = switch_force × (a/b) + spring_force × (c/b)`.
- **Pivot**: continuous 3 mm steel/brass rod spanning all keys, U-slot ears per key.
- **Key proportions**: 72 mm white / 44 mm black depth (for lever leverage + Casio SA / Yamaha
  PSS mini feel).
- Alternatives considered and rejected: direct-on-switch (too flat — *now chosen anyway for
  simplicity*), leaf spring (needs heat-treated steel), living hinge (≤1–2 mm travel, fatigue),
  rubber dome (inconsistent), capacitive (no tactile feedback, see 0001).

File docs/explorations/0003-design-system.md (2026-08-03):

# 0003 — Design system (measurement grid)

**Status:** decided, with a keyboard exception  ·  (`open → decided → revised`)

> **Revision (2026-06-18) — 280 mm frame.** The frame was shrunk from 320 mm to **280 mm**
> wide for a more pocketable device. A 2-octave keyboard at 20 mm pitch spans 300 mm and no
> longer fits, so the keyboard moved to **18 mm pitch** (15 white keys = 270 mm + 5 mm margins) *(since superseded: 24 keys at parametric 18.8 mm pitch — see the 2026-07-31 revision note below)*.
> This puts the keyboard **off the 4 mm grid** — which weakens the "decisive argument" below,
> since that argument was the main reason 4 mm beat 5 mm. The 4 mm grid is **retained for the
> shell, walls, control placement, and corner radii**; the keyboard is now an explicit, isolated
> exception in service of fitting two octaves into 280 mm. Tables below are updated to the new
> values; off-grid entries are marked.

> **Revision (2026-07) — OP-1 flat-cap pivot (V1).** The lever mechanism is deferred (see
> [0002-key-design.md](0002-key-design.md)); V1 uses flat rectangular caps directly on the
> switches. This **cuts keyboard depth from ~72 mm to ~35 mm** (natural cap ~20 mm front row +
> sharp back row at ~17 mm spacing), freeing ~35–40 mm inside the 160 mm frame. The pitch (18 mm)
> and span (270 mm) are unchanged. Nice side effect: the shorter flat-cap depths land back **on**
> the 4 mm grid (20 = 5×4, 16 = 4×4). The enclosure depth re-split (control band vs keys vs shelf)
> and the SVG still need updating to spend the reclaimed depth — tracked in consequences.

## Context

Physical products benefit from a base measurement unit — a grid that all dimensions snap to,
so spacing, proportions, and components feel harmonious rather than arbitrary. This is the
equivalent of the 8px/16px grid in UI design.

The question was: **4mm or 5mm base unit?**

## Decision

**4mm base grid.**

All dimensions should be multiples of 4mm. The enclosure, key proportions, control placement,
wall thicknesses, and gaps should all land on this grid.

## Why 4mm wins

### 1. Black key proportions — the decisive argument

Standard piano black key proportions: ~60% of white key width and ~60% of white key depth.
This is what makes a keyboard look and feel like a musical instrument.

With 20mm white key pitch (shared by both systems):

| Dimension | 4mm grid | 5mm grid |
|---|---|---|
| White key pitch | 20mm = 5×4 ✓ | 20mm = 4×5 ✓ |
| Black key width (60%) | **12mm = 3×4 ✓** | 10mm = 2×5 → 50% ✗, or 12mm off-grid ✗ |
| White key depth | 60mm = 15×4 ✓ | 60mm = 12×5 ✓ |
| Black key depth (60%) | **36mm = 9×4 ✓** | 35mm = 7×5 ~ok, or 40mm = 67% ✗ |

On a 5mm grid, the black key width has no clean solution: 10mm is too narrow (50%) and
12mm breaks the grid. The 4mm grid is the only one where the 60% piano ratio lands on clean
multiples for both width and depth.

> **Note (superseded):** this argument assumed 20mm pitch. The 280 mm frame revision dropped
> the keyboard to 18mm pitch, where the black key (~10mm) is off-grid regardless — so this
> particular point no longer holds for the keyboard. The other reasons (wall thicknesses,
> hardware fit) still favour 4mm for the rest of the device, so the base grid stands.

### 2. 3D printing wall thicknesses

FDM nozzle standard is 0.4mm. Structural walls are always multiples of that:
`0.8 → 1.2 → 1.6 → 2.0 → 2.4mm`. 4mm = 10× the nozzle diameter — walls, bosses, and
rails naturally align. 5mm has no relationship to FDM line width.

### 3. Common hardware dimensions fit cleanly

| Component | Dimension | On 4mm grid |
|---|---|---|
| EC11 encoder body | 24mm | 6×4 ✓ |
| Speaker (current 30mm → target 40mm) | 40mm | 10×4 ✓ |
| Natural cap depth (V1 flat) | 20mm | 5×4 ✓ |
| Sharp cap depth (V1 flat) | 16mm | 4×4 ✓ |
| Sharp cap width | 10mm | off-grid (18mm pitch) |

## Reference values

> **Revision (2026-07-31) — keyboard values superseded.** The cap/pitch figures below are superseded: pitch is now **parametric** (`pitch = cap + gap`; cap 1u = 18 mm + gap 0.8 mm = **18.8 mm** currently (rev. 2026-08-01)) and caps are sized in **1u = 18 mm units** per [`hardware/3d/keyboard/octaves-plan.md`](../../hardware/3d/keyboard/octaves-plan.md) §7 — the single source for keyboard geometry. The "keyboard on the 4 mm grid" argument no longer applies as such; the **4 mm grid still governs the rest of the enclosure** (shell, walls, controls, radii). Tables kept for the reasoning.

All key dimensions for the keyboard, at the revised **18mm pitch** (the pitch and span are off
the 4mm grid; the 16mm keycap and the depth dimensions land on it):

| Dimension | Value | Grid factor |
|---|---|---|
| White key pitch (center-to-center) | 18mm | 4.5×4 ⚠ off-grid |
| Natural cap width (keycap) | 16mm (pitch − 2mm gap, 1mm/side) | 4×4 ✓ |
| Sharp cap width | 10mm | off-grid (≈56%) |
| Sharp cap width ratio | ≈56% of pitch | — (60% rule = 10.8mm) |
| Natural cap depth (V1 flat) | 20mm | 5×4 ✓ |
| Sharp cap depth (V1 flat) | 16mm | 4×4 ✓ |
| Sharp↔natural row spacing (switch centers) | ~17mm | ⚠ off-grid (15mm body-clearance floor) |
| 15 natural keys total span | 270mm | 67.5×4 ⚠ off-grid |

V1 uses **flat rectangular caps** (OP-1 style, no lever — see [0002](0002-key-design.md)): two
rows, naturals in front, sharps offset behind. Cap depths (~20/16mm) are starting points and are
grid-clean (20 = 5×4, 16 = 4×4); only the 18mm pitch, 270mm span, and ~17mm row spacing are
off-grid. The deep 72/44mm piano-key depths belonged to the deferred lever design.

*(Previous values were 20mm pitch / 12mm black / 19mm visible / 300mm span at 60/36mm depth —
see the revision note at the top of this file.)*

### Enclosure outline

> **Revision (2026-07-31).** The keyboard-span figures below (270 mm span, 5 mm side margins, 15 naturals) assume the old fixed 18 mm pitch and 25 keys — superseded: at the current parametric 18.8 mm pitch the **24-key** front row is ≈ **262 mm** (per [`octaves-plan.md`](../../hardware/3d/keyboard/octaves-plan.md) §7), so the margins need re-deriving with the enclosure re-split. The 280×160 mm shell values on the 4 mm grid still stand as the working outline.

| Dimension | Value | Grid factor |
|---|---|---|
| Enclosure width | 280mm | 70×4 |
| Enclosure height | 160mm | 40×4 |

Width was reduced from 320mm to **280mm = 70×4** for a more pocketable device; both are clean
4mm multiples. The keyboard (now 270mm at 18mm pitch) sets the floor on width — see the margin
table below. The height was 150mm in early sketches, but 150 = 37.5×4 is **off-grid**. 160mm is
the nearest value that is both a clean 4mm multiple (40×4) and a whole number of 1cm grid cells,
and its 160mm depth splits as **86mm control band + 72mm keys + 2mm front shelf** (the keys
are pushed to the bottom edge, leaving only the shell's corner-radius clearance below them).
140mm (the other on-grid option) is too short — the 72mm keys plus the control band already
need ~158mm before any shelf.

> **⚠ Stale after the OP-1 pivot.** Flat caps need only ~35mm of keyboard depth (not 72mm), so
> this 86 / 72 / 2 split is superseded — the frame now has ~37mm of slack. The re-split (bigger
> control band? smaller frame? front shelf?) is an open follow-up, resolved together with the
> enclosure SVG update. 140mm becomes viable again if the frame is shrunk.

### Margins

| Margin | Value | Grid factor | Notes |
|---|---|---|---|
| Side wall → keyboard edge | 5mm | 1.25×4 ⚠ | absorbs the leftover from 280 − 270mm keyboard; the margin takes the half-unit (same kind of compromise as the old 10mm margin) |
| Top edge → keyboard top | 86mm | 21.5×4 ⚠ | the control zone (display, encoders, joystick, speaker) sits in this band; grew from 80mm when the keys were pushed to the bottom |
| Keyboard front → bottom edge | 2mm | 0.5×4 ⚠ | minimal front shelf — keys pushed as far down as the 8mm shell corner radius allows |

The off-grid values are now the keyboard itself (18mm pitch) and the 5mm side margin it leaves
(280 − 15×18 = 10mm total → 5mm per side). A true 4mm-clean margin isn't reachable while the
keyboard sits on an 18mm sub-pitch; the shell, control zone, and shelf remain grid-aligned.

### Corner radii

Multiples of 4mm for structural parts; 2mm (half-unit) allowed for small inset features only.

| Element | Radius | Grid factor |
|---|---|---|
| Enclosure shell | 8mm | 2×4 |
| Component cutouts (display bezel, joystick plate, speaker box) | 4mm | 1×4 |
| Inner insets (screen active area, speaker grille) | 2mm | half-unit |
| Piano keys (bottom corners only) | 2mm | half-unit |
| Black–white key separation (notch fillet) | 3mm concave / 1.5mm convex | r3 = key r2 + 1mm gap |

There is a **1mm gap between black and white keys**; the white-key notch fillet (r3) is
concentric with the black key's r2 bottom corner, so the separation stays a uniform 1mm all
the way around the corner.

## Consequences

- `docs/hardware/enclosure-layout.svg` — ✅ **updated 2026-08-01**: now draws the **v1.0 one-octave device** (184×120mm shell, 12 keys C–B at pitch 18.5 (drawn — pitch has since moved to 18.8, SVG pending), joystick left / top band display + 2 encoders + ø40 speaker), per [`hardware/3d/keyboard/octaves-plan.md`](../../hardware/3d/keyboard/octaves-plan.md) §8. The 280×160mm 2-octave layout this doc originally described is a future version; when it returns, derive it from octaves-plan, not from the superseded tables in this doc.
- `docs/explorations/0002-key-design.md` — ✅ pivoted to OP-1 flat caps: 2-octave **24-key** grid (C3–B4); current cap/pitch geometry lives in [`octaves-plan.md`](../../hardware/3d/keyboard/octaves-plan.md) §7 (1u = 18mm caps, parametric pitch 18.8mm); lever design deferred.
- Enclosure width must accommodate the 270mm keyboard + margins (5mm each side → 280mm = 70×4);
  height is 160mm = 40×4 (see table above)
- All 3D print files: walls in multiples of 0.8mm, bosses/rails in multiples of 4mm

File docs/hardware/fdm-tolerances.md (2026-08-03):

# FDM fits & tolerances — project reference

Working reference for every printed part in this project. The **calibrated, print-validated values live in [`hardware/3d/keyboard/octaves-plan.md`](../../hardware/3d/keyboard/octaves-plan.md) §2 — never re-derive those**; this doc covers the general rules for the fits we haven't calibrated yet (enclosure, inserts, snap-fits). Deep theory lives in the external cad-lab repo (not part of this repo).

## Validated on this project (source: octaves-plan §2)

| Fit | Value | Context |
|---|---|---|
| KS-33 plate cutout kerf | **0.0** | PLA + PETG, 0.2 & 0.4 mm nozzles, 3 print services — fit passed as-modeled |
| Cap stem clearance | **0.18** FDM / 0.05 resin | on cross-arm width only, with 0.5 mm `mouth_flare` 45° lead-in |
| Elephant foot | present on 1 of 3 services | countermeasure: **0.3 mm chamfer** (≈ first layer height + margin; 0.3–0.5 range, dial up only if a printer's foot is worse). On flat plates, chamfer **both faces** so print orientation can't leave a raw edge |

Lesson: kerf on *this* printer chain is near zero — but every new mating geometry still gets a **parameter + test coupon** before the full part (that's how the values above were earned).

## General rules for the next parts

**Clearance fits (hole/slot larger than the inserted part):**

| Fit type | Clearance per side | Use |
|---|---|---|
| Press / snug | 0.0–0.1 mm | parts that must not rattle (switch cutouts — validated at 0 here) |
| Sliding | 0.2–0.3 mm | display/module drop-in pockets, perfboard seats |
| Free / loose | 0.4–0.5 mm | anything hand-assembled blind, cable pass-throughs |

**Holes print undersized** (0.2–0.4 mm on FDM, worse on small diameters): model holes with a diameter parameter and calibrate — never trust nominal. Vertical-axis holes are rounder than horizontal ones; horizontal holes sag at the top.

**M2 fasteners (the project standard):**

- Through-hole clearance: **ø2.2** (validated — octaves-plan screw spec).
- Self-tapping into a printed boss: **ø1.8** pilot, boss wall ≥ 2 mm around the hole.
- **Heat-set insert (enclosure side of the sandwich):** hole per the insert's datasheet — typical M2 short insert wants **ø3.1–3.2**, depth = insert length + ~1 mm; boss OD ≥ insert OD + 2× 1.6 mm wall. Buy the inserts first, then model from the measured spec.

**Snap-fits (the plate wire channels):** slot for the 1.4 mm bus wire starts at **1.4 + kerf** (1.6 initial); for retention, neck the opening to ~**1.2** (≈85% of the captured diameter) and widen inside. Flexing walls ≥ 1.2 mm thick; never put a snap-fit's flex direction across layer lines.

**Printability constraints that shape fits:**

- Overhangs ≤ 45°, bridges ≤ ~20 mm — design pockets stepped (like `ks33_cutout`) so every face rests on solid material in the chosen print orientation.
- State the intended **print orientation** in the part file; fits are orientation-dependent (a slot that's clean printed vertically sags printed flat).
- Walls ≥ 2 perimeters of the nozzle (≥ 0.8 mm at 0.4, ≥ 1.2 mm structural).

**Process:** for each new mating feature → expose a clearance parameter → print a coupon (only the feature, minutes not hours) → lock the value → record it in octaves-plan §2 so it joins the "don't re-derive" table.

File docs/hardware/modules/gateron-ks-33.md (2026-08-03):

# Gateron KS-33 Low Profile 2.0 — Silent Brown

Low-profile mechanical switch used for the keyboard keys. Silent tactile, pre-lubed, hot-swappable, with an **MX-style cross stem** and a low-profile body designed for a thin plate. One switch per key; actuated directly by a printed keycap (no lever bridge — see the OP-1-style key direction).

<a href="https://www.gateron.com/products/gateron-ks-33-low-profile-red-silent-20-mechanical-switches-set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">Gateron KS-33 Low Profile 2.0 Silent switch</a>

*Gateron KS-33 Low Profile 2.0 Silent (product image; Silent White shown — Silent Brown has the same body with a tactile brown stem).*

| | |
| --- | --- |
| **Role** | Per-key mechanical switch (keyboard) |
| **Model** | Gateron KS-33 Low Profile 2.0, **Silent Brown** |
| **Feel** | Silent **tactile**, **55 gf** (±15 gf) operating force, factory pre-lubed |
| **Travel** | Pre-travel **1.7 mm**, total **3.0 ±0.2 mm** |
| **Stem** | **MX-style cross ("+")**, low-profile — brown, POM |
| **Mount** | 3-pin: 2 metal contact pins + 1 central plastic locating post; plate-mount clips on the sides. 3-pin confirmed on our units by photo + purchase listing (some Gateron marketing text for the range says "5-pin") |
| **Hot-swap** | Yes (designed for low-profile hot-swap sockets) |
| **Plate** | Designed for a **1.2 mm** low-profile plate |
| **LED** | SMD LED slot, south-facing (pairs with [SK6812 MINI-E](sk6812mini-e.md)) |
| **Housing** | PC transparent top, nylon black bottom, POM stem |
| **Compatibility** | NOT interchangeable with standard MX or Kailh low-profile switches (different body) |

*Specs confirmed against Gateron's official product page. Reference (same family): Silent Red = linear 45 gf; Silent Brown = tactile 55 gf. Same 1.7 mm / 3.0 mm travel across the line.*

> ✅ **Dimensional drawing obtained** ("Gateron Low Profile" dimensional drawing, via Ranked) — full mechanical dimensions in the [Mechanical dimensions](#mechanical-dimensions-from-drawing) section below. The drawing is labeled generically "Gateron Low Profile", so a quick **caliper sanity-check** was done. Gateron's own product page and the bundled PDF still publish no drawing.
>
> ⚠️ **The drawing + STEP are the STANDARD KS-33 LP 2.0 — NOT the Silent** we actually have. They differ (stem top detail; Silent body is ~0.5 mm smaller). See the vernier-measured Silent values below — **those are the source of truth for the build.**

## Anatomy / glossary

Terms used throughout the keyboard design:

- **Switch** — the whole component ("shaft"/"eje" in some listings). Houses spring + contacts.
- **Stem** — the moving part that travels up/down when pressed. On the KS-33 it's the **brown "+" cross** (MX-compatible). The keycap mounts here.
- **Keycap / cap** — the plastic top you touch with your finger; clips onto the stem cross. In this project these are **3D-printed, rectangular, OP-1 style**.
- **Nub** — a small protrusion. Not a stock switch part — a feature the *floating-cap* route would have added under the cap to push the stem down (that route was considered and dropped — see "Keycap strategy").
- **Pins** — the 2 metal contacts (electrical) + 1 central plastic post (mechanical alignment) = the "3-pin" spec.

```
   keycap  ──▶ ┌────────┐   rectangular, printed
               └──┐  ┌──┘
   stem "+" ──▶    ╋       MX cross, moves down
               ┌────────┐
   housing ──▶ │  ▢▢▢   │  spring + contacts inside
               └─┬─┬─┬──┘
   2 metal pins ─┘ │ └─── + central plastic post ("3-pin")
```

## Mechanical dimensions (from drawing)

<a href="https://www.amazon.com/dp/B0BW63X3R2">Gateron KS-33 Low Profile dimensional drawing</a>

*Dimensional drawing (source: Amazon listing). Confirms the side-view stack: 1.20 mm plate notch · 2.50 mm flange-to-base · 14.00 mm cutout · 14.70 mm outer.*

From the Gateron Low Profile dimensional drawing (all mm) — annotated drawing via Ranked, cross-checked against the vernier measurements above. Gateron publishes CAD/3D models and spec sheets at [gateron.com/pages/3d](https://www.gateron.com/pages/3d) and [product-specification](https://www.gateron.com/pages/product-specification).

**Official 3D model (authoritative geometry):** Gateron provides a **STEP (`.stp`)** file — [KS-33 Low Profile 2.0 3D (.rar)](https://www.gateron.com/u_file/2309/25/file/GateronKS-33LowProfile20KS33-20230109KS-33-Y313D.rar) (from the [3D models page](https://www.gateron.com/pages/3d)). Import into **FreeCAD / KiCad** for the exact stem + body geometry — the source of truth for the cap socket, plate cutout, and the KiCad footprint's 3D view. *(The `.stp` itself is not committed; a converted STL for visual ghosting lives at [`hardware/3d/vendor/ks33-switch.stl`](../../../hardware/3d/vendor/README.md) — standard KS-33, not the Silent, visual only.)*

**Body & mounting**

| Dimension | Value |
| --- | --- |
| Top housing (body) footprint | 15.00 × 15.00 |
| **Plate cutout** (body passes through; 15 mm flange rests on top) | **14.00 ±0.03** |
| **Plate thickness** (clip engages this) | **1.20 ±0.05** |
| Overall height | ~12.15 (+0.20/−0) |

**Stem (keycap mount)** — MX-style cross, but model printed caps to these *exact* numbers, not generic MX:

| Dimension | Value |
| --- | --- |
| Cross envelope | 4.00 × 4.00 (±0.05) |
| Cross arm widths | 1.10 ±0.04 (vertical) and 1.23 ±0.04 (horizontal, LED side) — *earlier docs misread the wide arm as 1.28; corrected 2026-08-01 against the drawing + vernier (1.1 × 1.2)* |
| Stem collar diameter | ø5.70 ±0.05 |
| Keycap-mount tower height | **2.95 mm** — sliced from the STEP; cross + collar + boss all reach the same top plane (z=12.15). **This caps the cap socket depth.** |

> **The keycap mount is standard MX.** Gateron: *"MX-styled stem with a circular dust wall"*, compatible with standard MX keycaps ([gateron.co](https://www.gateron.co/products/gateron-low-profile-mechanical-switch-set)). So the **housing/boss shape (square vs rectangular) is irrelevant to the cap** — the cap only engages the **cross ("+") + the circular collar**, and both are standard (**cross 4.0 × 1.1, collar ø5.7**). Verified by slicing the official STEP: cross **4.00 × 1.11** arm, collar **ø5.68**. The *one* non-standard trait is **low profile** — the mount tower is only **~2.95 mm** tall, so the cap socket must be shorter than the full-MX ~4 mm.

**Bottom / PCB footprint (hot-swap)** — only relevant if a PCB version happens (deferred; build 1.0 is hand-wired, no PCB). Transcribe directly into the PCB footprint:

- Central pole at center, ø ~4.80–5.05 (minor rev variation between drawing sheets).
- Metal contact pins + RGB LED slot positioned by offsets: 5.00, 3.20, 2.25, 5.75, 4.70, 2.60, 4.40 (from center).
- RGB (SMD LED) slot on the **south** side — sets where the [SK6812 MINI-E](sk6812mini-e.md) sits relative to switch center.

**Under-plate protrusion (sliced from the official STEP, 2026-08-02)** — what hangs below the 2.4 mm stepped plate when the switch is seated (flange on plate top, below-flange body 2.5 tall → housing base ≈ 0.1 proud of the plate bottom):

| Feature | Below housing base | Below plate bottom |
| --- | --- | --- |
| Bottom centre pillar (ø4.9) | 3.3 | **3.4** — the deepest hard feature |
| Metal contact pins (tips) | 2.6 | **2.7** (+ solder when hand-wired) |

**Pin positions (sliced from the STEP, 2026-08-02):** both pins sit in the switch's **south half** — (−4.4, −4.7) and (2.6, −5.75) from the switch centre (x = east, y = north). A switch can be rotated in the square plate cutout to point its pins away from whatever runs underneath.

**PCF8575 mount consequence (settled 2026-08-02):** the module mounts **vertically in the D#↔F# bay**, clear of every pillar — so the standoff in `plate.scad` dropped from 4.0 (old pillar floor) to **2.8** (new floor = the module's right-angle I2C header body 2.5 + 0.3 air). **Assembly rule: D# turns −90° (pins WEST) and F# +90° (pins EAST)** so their pins + solder point away from the board.

**Layout implication:** body is 15.00 mm and the natural (1u) pitch is 18.5 mm (18 mm cap + 0.5 mm gap) → **3.5 mm between switch bodies** (1.75 mm/side) and **4.5 mm of plate web between 14 mm cutouts**. Tight but workable. The 1.5u sharps (27 mm caps) sit on wider spacings, so their plate webs differ — see [`hardware/3d/keyboard/octaves-plan.md`](../../../hardware/3d/keyboard/octaves-plan.md).

### Silent variant — vernier measurements (SOURCE OF TRUTH)

The STEP/drawing above are the **standard** KS-33 LP 2.0. Our actual switch is the **Silent Brown**, which is slightly different. Measured on the physical Silent switch — **use these for CAD**:

| Feature | Silent (vernier) | Standard (model) |
|---|---|---|
| Outer flange — widest, rests on plate | **14.5 mm** | 15.0 |
| Below-flange body — passes through plate | **13.9 × 13.9 mm** | ~14 |
| Housing height (excl. bottom pillar + stem) | **5.2 mm** | — |
| Bottom centre round pillar (ø) | **4.9 mm** | ~4.8–5.05 |
| Stem top (the moving part, rounded-rectangle) | **6.4 × 6.2 mm** | round-ish |
| Cross arm width | **~1.0 mm** (re-measured: 1.1 × 1.2) | 1.10 / 1.23 |
| Stem top difference | clean cross on rounded base | cross + centre detail |

**For CAD:**
- **Plate cutout:** target **~14.0 mm** (below-flange 13.9 passes; flange 14.5 rests on top). Dial exactly on the single-key test print.
- **Plate thickness — DECIDED: 2.4 mm stepped plate, no PCB underneath.** The keyboard is **plate-mount, hand-wired** to the PCF8575 — there is no PCB, so the plate alone carries the switches and the clips do all the retention (nothing rests on a board below). The **1.2 mm clip shelf is the critical reference**; the rest is structural:
  - **Top 1.2 mm:** 14.0 mm hole = the **clip shelf** (body passes, clips hook under this ledge — matches the switch's 1.2 mm plate spec).
  - **Lower 1.2 mm:** widen to **15.2 mm** to clear the 15 mm body and the sprung-out clips (~14.7 mm hooked). Total 2.4 mm prints far sturdier than a bare 1.2 mm plate.
  - These values are **print-validated** (kerf 0.0, PLA/PETG, multiple print services) — see [`hardware/3d/keyboard/octaves-plan.md`](../../../hardware/3d/keyboard/octaves-plan.md) §2 (calibrated values) and §5–6 (rebuild file structure + enclosure context). Switch pins are hand-wired point-to-point below the plate; wire channels in the plate underside route the runs to the PCF8575, which mounts into the plate's sharps-row bays.
  - Per-key SK6812 LEDs are **deferred** — they require a PCB version of the keyboard; build 1.0 has no LEDs, so the plate needs no LED provisions.
- **Cap cross-socket (finalised 2026-08-01 — source of truth: `hardware/3d/keyboard/key_cap.scad`):** standard MX cross-in-cylinder mount — **post Ø5.5** (matches collar ø5.7), **socket depth 2.8 mm** (tower is 2.95 — do NOT adopt Cherry's 3.6/3.8 full-MX depths). Bore is **per-arm**: stem arms 1.10 (vertical) / 1.23 (horizontal) + clearances **0.18 / 0.05** → **both slots 1.28 mm** — exactly the print-validated fit (PLA/PETG, 0.2 & 0.4 nozzles), and equal slots keep cap orientation free (no LED-north constraint). Bore length **4.1** (stem 4.0 + 0.1, official Cherry cap spec) with **R0.3 inner-corner fillets** (official cap spec; avoids FDM corner cracks). The common symmetric **1.17** slot is for injection POM/ABS (interference grip) — too tight for stiff FDM PLA. **0.2 mm 45° flared lead-in** at the mouth (official cap spec); optional **split-post** for FDM so the cross flexes instead of cracking.
- The STEP model is a **rough visual reference only** for the Silent — geometry authority is this table.

## Keycap strategy (this project)

**Decided: stem-mounted cap** — printed cap with a cross socket on the MX stem, plus a plate guide rib for anti-rotation; the floating-cap route was considered and dropped ([0002-key-design.md](../../explorations/0002-key-design.md)).

Socket geometry and print-calibrated clearances: [`hardware/3d/keyboard/octaves-plan.md`](../../../hardware/3d/keyboard/octaves-plan.md) §7.

## Wiring (to the keyboard I2C expanders)

Direct wiring, no matrix, no diodes:

- One leg of each switch → one input pin of a [PCF8575](pcf8575.md) I2C expander. The PCF8575 ports are quasi-bidirectional: each pin has a **weak current source to VCC** (not a true internal pull-up) that the switch pulls low — no external pull-ups needed on the P-pins (see [pcf8575.md](pcf8575.md#how-the-quasi-bidirectional-io-works)).
- Other leg → common GND.
- Press = pin reads LOW. Each key is independent (32 inputs across 2× PCF8575), so no ghosting and no diodes needed.

## Sources

- **Official Gateron product page** (spec table — force, travel, materials, pins): https://www.gateron.com/products/gateron-ks-33-low-profile-red-silent-20-mechanical-switches-set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
- Gateron KS-33 datasheet index (PDFs per color, no mechanical drawing): https://www.gateron.co/pages/gateron-ks-33-low-profile-2-0-mechanical-switch-datasheet
- Bundled "Product Manual" PDF: generic CE/RoHS safety manual only — **no mechanical data**.
- Keebio product page (secondary): https://keeb.io/products/gateron-ks-33-low-profile-2-0-switches

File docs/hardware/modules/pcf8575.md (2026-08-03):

# PCF8575 — 16-bit I2C I/O Expander

16-bit GPIO expander over I2C. Two PCF8575s read the 24-key keyboard (C3–B4) using only 2 ESP32-S3 pins (SDA + SCL), leaving native GPIOs free for encoders, display, and audio. See [wiring.md](../wiring.md#pcf8575--16-bit-i2c-io-expander-keyboard-2-chips) for the full key-to-pin map.

| | |
| --- | --- |
| **Role** | Keyboard input — chip #1: 16 keys (C3–D#4, 0 spare); chip #2: 8 keys (E4–B4) on P00–P07, 8 spare |
| **Chip / variant on hand** | PCF8575CTS (NXP) on the blue 21×32 breakout — see [Mechanical](#mechanical--v10-module-measured-2026-08-01); electrical sections below were written for the SparkFun BOB-08130 |
| **Interface** | I2C (SMBus compatible), up to 400 kHz |
| **Operating voltage** | 2.5 V – 5.5 V (3.3 V used here) |
| **Source** | — |
| **Price** | — |
| **Quantity** | 2 used in design (5 ordered, 1 on hand) |

## Datasheets & references

- TI datasheet (SCPS121I): https://www.ti.com/lit/ds/symlink/pcf8575.pdf
- SparkFun breakout repo (BOB-08130): https://github.com/sparkfun/I2C_Expander_Breakout-PCF8575
- SparkFun product page: https://www.sparkfun.com/products/8130

## Photos

SparkFun PCF8575 I2C Expander Breakout

> Source / credit: [SparkFun Electronics](https://www.sparkfun.com/products/8130)

## Mechanical — v1.0 module, measured (2026-08-01)

The module used for the v1.0 build is **not** the SparkFun breakout above but the common blue 21×32 breakout (NXP PCF8575CTS, AMS1117-3.3 regulator, 2× 7002 FETs, 103 resistor network on board). Values below: board outline **vernier-measured on the physical module**; hole/header positions extracted from the [GrabCAD STEP](https://grabcad.com/library/module-pcf8575-16bit-io-expander-1) (community model) which **cross-checks against both the vernier outline and the listing photo** — hole ø and hole-to-edge still pending a physical dry-fit before committing prints. A converted STL for visual ghosting is committed at [`hardware/3d/vendor/pcf8575-module.stl`](../../../hardware/3d/vendor/README.md).

| Param | Value | Source |
| --- | --- | --- |
| Board outline | **32.1 × 21.3 mm** (STEP: 32.3 × 21.5) | vernier |
| Board thickness | 1.6 mm | STEP |
| Mounting holes | **4× ø2.0** | STEP — verify ø accepts M2 before printing bosses |
| Hole pitch, long axis | **28.30 mm** (pitch-true PCB drill — trustworthy) | STEP |
| Hole pair span, 5-pin end | 17.00 mm (corner pair, 2.3 from short edge, 2.25 from long edges) | STEP |
| Hole pair span, far end | 6.50 mm (mid-edge pair, 1.7 from short edge, centered on width) | STEP |
| Pin rows | 2× 10 pins, 2.54 pitch, rows 1.86 mm in from each long edge; first pin 7.2 mm from the 5-pin edge | STEP |
| 5-pin column (INT/SCL/SDA/VCC/GND) | 2.54 pitch, 1.2 mm in from its short edge, centered on width | STEP |
| Tallest component (top) | **2.1 mm** (PCF8575 SSOP); AMS1117 1.5 in STEP but SOT-223 nominal max ≈ 1.8 — design standoffs for **≥ 2.2, use 2.5–3** | STEP + datasheet |
| Bottom side | flat (all SMD on top) — but hand-soldered wire joints will protrude ~2 mm on whichever side you solder from | STEP |

**Plate-mount fit (build 1.0 — SETTLED 2026-08-02):** the module mounts **VERTICAL in the D#↔F# bay** (centre x = bay centre, y = 24.0; long axis along Y, I2C-header end north) — the pillar-free spot: the board clears every KS-33 under-plate pillar, and D#/F# rotate ±90° so their pins point away (see `gateron-ks-33.md`). South (mid) hole pair lands in the naturals↔sharps web; north (corner/header) pair on a small **back tab** grown off the plate edge. Mount values in `plate.scad`: bosses ø4.4, pilot ø1.8×3.8, **standoff 2.8** (floor = right-angle header body 2.5 + 0.3), screws **M2×5** (3.4 mm thread). Component side + a 90° male header on the 5-pin I2C column face the **plate**; solder face + header tails point outward. The earlier horizontal spanning of both bays (boss ring ø6 vs SSOP corner conflict) is superseded.

**⚠ Electrical notes below were written for the bare SparkFun BOB-08130.** The blue module carries an AMS1117-3.3 (VCC can be 5 V), FET level shifters on SDA/SCL, and a 10 k resistor network (likely onboard I2C pull-ups) — and does not expose A0/A1/A2 as pins. Verify pull-ups/address on the physical board before adding external parts.

## Module pins

| Pin | Type | Description |
| --- | --- | --- |
| VCC | PWR | Supply voltage. Connect to 3.3 V. |
| GND | PWR | Ground. |
| SDA | I/O | I2C data. Requires external pull-up to VCC (4.7 kΩ). |
| SCL | I | I2C clock. Requires external pull-up to VCC (4.7 kΩ). |
| INT | O | Interrupt output (open-drain, active-low). Pulses low when any input changes. Requires pull-up to VCC. |
| A0, A1, A2 | I | I2C address select. Tie directly to VCC or GND — no pull-ups needed. |
| P00–P07 | I/O | Port 0, 8 quasi-bidirectional I/O pins. |
| P10–P17 | I/O | Port 1, 8 quasi-bidirectional I/O pins. (Note: naming jumps from P07 to P10 — there is no P08 or P09.) |

## I2C address

Address = `0x20 | (A2 << 2) | (A1 << 1) | A0`.

| A2 | A1 | A0 | Address |
| --- | --- | --- | --- |
| GND | GND | GND | 0x20 (default) |
| GND | GND | VCC | 0x21 |
| … | … | … | 0x22–0x27 |

Up to 8 devices on one bus. Default (all address pins to GND) = **0x20**.

## Key electrical limits

| Parameter | Value |
| --- | --- |
| Supply voltage | 2.5 V – 5.5 V |
| P-port sink current (IOL) | 25 mA max |
| P-port source current (IOH) | −1 mA typ (weak) |
| Standby current | 10 µA max |
| I2C max clock | 400 kHz |

## How the quasi-bidirectional I/O works

Each P-pin has a weak current source to VCC and a strong pull-down. At power-on all pins default **HIGH**.

- **Read (input mode):** write `1` to the pin (or leave it at power-on default). An external signal can then pull the pin low against the weak source. Read the pin state back via I2C.
- **Write (output mode):** write `0` to pull the pin low hard (25 mA sink); write `1` to release it to the weak high.

For key reading: wire each key between a P-pin and GND. Pin reads `1` when the key is open; `0` when pressed. No need to write anything first — the power-on default is already the correct input state.

## Reading keys

A single 2-byte I2C read returns all 16 pins at once. Port 0 (P00–P07) arrives in the first byte (LSB = P00), port 1 (P10–P17) in the second byte (LSB = P10).

```cpp
uint16_t readAll(uint8_t addr = 0x20) {
    Wire.requestFrom(addr, (uint8_t)2);
    uint8_t lo = Wire.read();   // P00–P07
    uint8_t hi = Wire.read();   // P10–P17
    return (uint16_t)lo | ((uint16_t)hi << 8);
}
// key N is pressed when bit N of the return value is 0
```

## Interrupt-driven scanning

Connect INT to a free ESP32-S3 GPIO. Attach a falling-edge interrupt. In the ISR (or a flag it sets), do one `Wire.requestFrom()` to read all 16 bits and find which key changed. Avoids polling the I2C bus every loop iteration.

## Notes & gotchas

- **External pull-ups required.** The SparkFun BOB-08130 breakout is bare — it does not include SDA/SCL pull-ups. Add 4.7 kΩ from SDA to 3.3 V and SCL to 3.3 V on the breadboard. Without them the bus will not work.
- **INT is open-drain.** Add a pull-up (4.7–10 kΩ to 3.3 V) on the INT line, or enable the ESP32-S3's internal pull-up on the INT GPIO.
- **Port naming:** the second port is P10–P17, not P08–P15. The `7` in P07 and `10` in P10 are decimal digit pairs (port·pin), not hex. Easy to misread when building bit masks.
- **3.3 V safe.** VCC = 3.3 V is within the 2.5–5.5 V range. The weak high output is also 3.3 V — no level shifting needed between the PCF8575 and the ESP32-S3.
- **I2C bus shared.** The PCF8575 shares SDA/SCL with any other I2C devices added later. Address conflicts are possible — A0/A1/A2 let you resolve them.
- Connections to the ESP32-S3 → see [../wiring.md](../wiring.md#connections).

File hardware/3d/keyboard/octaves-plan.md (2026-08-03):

# Octaves plan — handoff from the cad-lab FreeCAD exercise (2026-07-31)

The FreeCAD parametric replica of `plate-octave.scad` (cad-lab, `projects/groovebox-octave-plate/`) got paused — the tool fought back more than it taught. This doc carries over everything the exercise produced that this repo doesn't have yet, so the plate work finishes here in OpenSCAD.

## 1. The `octaves` parameter (the main deliverable)

Generalize the plate to N side-by-side octaves. The insight: with the plate, screws and caps all **derived from the key list bounding box** (which `plate-octave.scad` already does), the only real change is generating a multi-octave key list — everything else scales for free.

**`octave-layout.scad`** — add octave-aware helpers, keep the old names working (defaults preserve the existing caller: `assembly-octave.scad`):

```scad
function shift_key(k, o) = [k[0] + o*7, k[1], k[2], k[3]];
function layout_keys(octaves = 1)     = [ for (o = [0:octaves-1], k = oct_keys)     shift_key(k, o) ];
function layout_naturals(octaves = 1) = [ for (o = [0:octaves-1], k = oct_naturals) shift_key(k, o) ];
function layout_sharps(octaves = 1)   = [ for (o = [0:octaves-1], k = oct_sharps)   shift_key(k, o) ];

// centre the WHOLE keyboard on x=0: 3.5 key-units per octave
function key_x(k, pitch, octaves = 1) = (k[0] - 3.5 * octaves) * pitch;
```

**`plate-octave.scad`** — add `octaves = 1;` to the Customizer params, then swap `oct_keys` → `layout_keys(octaves)` (same for naturals/sharps in the cap preview) and pass `octaves` to every `key_x` call. The bbox loops (`cxmin`…`cymax`), plate size and corner screws need **no changes** — they derive from the key list.

**Centre screw** becomes one per octave (at each octave's centre, in the inter-row gap):

```scad
centre = screw_center ? [ for (o = [0:octaves-1]) [ (o*7 + 3.5 - 3.5*octaves) * pitch, screw_cy ] ] : [];
```

At `octaves = 1` this evaluates to the current single `[0, screw_cy]` — no behavior change.

**Sanity check** after wiring it: `octaves = 2` → echo should report 24 keys and 6 screws; `octaves = 1` → 12 keys (= build 1.0, see §8). Plate size: derive from the cap bbox, don't hand-check a number — the old ≈268.5 × 57.5 mm figure was computed at v0's pitch 19 and is stale since the pitch moved to 18.8 (§7). The old "byte-identical to v0's STL" check no longer applies for the same reason (and no STL is committed anymore).

## 2. Known-good values — calibrated, don't re-derive

All already in `plate-octave.scad` / `switch-cutout.scad`; listed so nobody "improves" them:

| Param | Value | Why |
|---|---|---|
| `hole_t` | 14.0 | KS-33 standard plate cutout |
| `hole_b` | 15.2 | clears the 15 mm switch body — **independent value**, never derive it as `hole_t + shelf` (numeric coincidence today; deriving would silently move the pocket if `shelf` changes) |
| `shelf` | 1.2 | KS-33 clip geometry (plate-thickness spec) |
| `kerf` | 0.0 | print-validated (PLA/PETG, 0.2 & 0.4 mm nozzles, 3 print services); + looser / − tighter |
| `thick` | 2.4 | = shelf 1.2 + pocket 1.2 |
| `screw_d` / `cs_d` | 2.2 / 4.0 | M2 clearance + flat-head countersink, 90° cone |

## 3. Lessons worth keeping (from the FreeCAD detour)

- **Derive, don't hand-formula.** The FreeCAD model hand-computed plate depth and shipped a 0.5 mm bug (57.0 vs 57.5). The SCAD's bbox-from-caps approach never had it. Keep deriving.
- **Print orientation**: model keyboard-up (as this repo does), flip 180° about Y in the slicer — each cutout step rests on solid material (no bridging), the cosmetic keyboard face gets the textured build plate, and the 90° countersink prints as a clean 45° overhang.
- **Sharps structure** (info, list-driven here anyway): the "irregular" row is two regular groups — C#–D# spaced 1.5·pitch, F#–G#–A# spaced 1.25·pitch.

## 4. Architecture decision (2026-07-31): NO custom PCB

V1 keyboard = **plate + switches hand-wired to the PCF8575 module**. No KiCad keyboard PCB. Consequences for the plate design:

- **PCF8575 mounts INTO the plate** (no separate carrier backplate). ✅ **Measured (2026-08-01)**: board 32.1 × 21.3 × 1.6 (vernier) — hole/header positions from the [GrabCAD STEP](https://grabcad.com/library/module-pcf8575-16bit-io-expander-1), cross-checked against vernier + listing photo; full dims in [`pcf8575.md` § Mechanical](../../../docs/hardware/modules/pcf8575.md#mechanical--v10-module-measured-2026-08-01): **4× ø2.0 holes, long-axis hole pitch 28.30**, pair spans 17.0 (corner/header pair) / 6.5 (mid pair), tallest component 2.1. Pending: verify hole ø accepts M2 at dry-fit. ✅ **Placement SETTLED (2026-08-02, in `plate.scad`)**: module **VERTICAL in the D#↔F# bay** (cx = bay centre, cy 24.4 — moved +0.4 north the same day so the boss root coves 0.4 clear the pockets and the trunk channel; header end north) — the **pillar-free spot**: the board clears every KS-33 under-plate pillar, and **D#/F# rotate ±90° so their pins point away** (rule in `gateron-ks-33.md`). South pair in the naturals↔sharps web; north (header) pair on a **derived back tab** (24.6 wide, +3.15 past the back edge). Bosses ø4.4 (0.4 grid), pilot ø1.8×3.8, **standoff 2.8** (floor = right-angle I2C header body 2.5 + 0.3), **screws M2×5**; component side + 90° header face the plate, solder face out. Under-plate stack 4.4. The original horizontal both-bay spanning is superseded (ø6 boss ring vs SSOP corner).
- **Wire channels in the plate underside** for the 1.4 mm copper bus wire: slot width `1.4 + kerf` (start 1.6), depth ~1.6–1.8. For snap-in retention: neck the opening to ~1.2 and widen inside — mini snap-fit, same kerf-calibration logic as the switch cutouts. Routes: switch pins → PCF. ✅ **Routed for real (2026-08-03)**: the generic trunk+spurs were replaced by the actual electrical routing designed in [`wiring-plan.svg`](wiring-plan.svg) (soldering view — from below, C right; solid = channel, dashed = wire in air) and carried into `plate.scad` as per-octave route data with generic clearance asserts. ✅ **SVG polished with the user + FROZEN (2026-08-03)** — final routing: web lanes at the **exact PCF pin heights** (Δ2.54 · model y 18.01/15.47/12.93/10.39, straight entry into every pin), pin map **C→P04 D→P05 E→P06 F→P07 C#→P02 D#→P01 / A→P10 B→P11 A#→P12 G#→P13 F#→P15 G→P17** (free P00·P03·P14·P16), **A#/G# switch pins inverted** (signal = left, GND = right in the soldering view) so the left GND chain (GND→F#→G#→A#→side drop→B→gutter) runs flat at pin height with an S centered in the F#–G# web; right GND chain crosses high at D#-pin height over C# and Z-descends inside the C#–C web onto C's pin line; front gutter centered (ends x ±63, 1mm inside the outer pocket corners); two under-board routes (G→P17 **between the south bosses** — 2.1 gap vs 1.6 channel — and F→P07 over the E pocket at the pillar limit); C#→P02 flat at its pin height. ✅ **Re-translated into `plate.scad` + iterated live with the user (2026-08-03)** — routes are polylines with **swept 90° bends** (`chan_bend 1.2`), pin-height lanes **derived** from `pcf8575.md` (rows 1.86 in from the long edges, GND 7.2 from the 5-pin edge, Δ2.54). Deltas vs the frozen SVG (the scad route data is now the **routing source of truth**; SVG re-sync pending): naturals GND runs in channels — the gutter's ends curl 90° into the C/B GND pins and **double-width spur tees** (2.8 = 2 cables in+out, each with its own 90° sweep) reach D–A; **F→P07 got a real under-board climb** at the P0x row x; G's F-crossing lowered to **y 5.2**; slot slimmed to **1.4 × 1.2** (wire 0.2 proud, snug not covered) with **0.3 mouth chamfer (`chan_rim`) + rounded half-revolved end caps**, the ø2 pocket mouths deleted; **`hole_rim 0.3`** 45° break on the pocket rims of the channel face; **C#|D# back foot dropped** (the GND high passage owns that web — 6 feet remain) and the back foot moved **G#|A# → F#|G#** (`gnd_sdrop_drop 1.2`: the S-drop's top leg ducks below F#'s pin height to clear the foot); header tails **trimmed after soldering** (1.0) → **feet 6.0**, and every foot carries an **M2 pilot (ø1.8×5.2 — M2×6 on a 2.4 deck / M2×8 on 3.2–4.0)** — the feet double as **deck-mount bosses** for the pre-enclosure integration deck (a future `deck.scad` derives the pattern from the `plate_feet()`/`plate_bbox()` accessors). `plate.stl` exported for the batch-2 print. ✅ **Cleanup session (2026-08-03)**: `hardware/3d/` restructured by module family (`keyboard/` + `vendor/` — third-party meshes KEPT + committed, provenance in `vendor/README.md`); ghost composition moved to `assembly.scad` (parametric default + vendor meshes opt-in), `plate-pcf-fit.scad` deleted; settled params frozen under `/* [Hidden] */` (Customizer = real knobs only: plate `octaves`/`kerf`/`feet` — the section cutaways were dropped as not useful · cap `part`/`split_post`/`section` · assembly view flags), geometry verified unchanged vs the in-print STL; `wiring-plan.svg` re-synced to the as-built routing (gutter end-curls + D–A double tees, F climb, G at y 5.2, slot 1.4×1.2+rim) — cleanup session COMPLETE, ready to commit.
- **Plate ↔ enclosure**: the M2 screws are the sandwich (plate + enclosure, heat-set inserts in the enclosure) — plate outline/screws must stay compatible with the future enclosure interface.
- ✅ **Resolved (2026-07-31)**: the per-key SK6812 LED plan assumed a PCB — **LEDs are deferred to a future PCB version**. Build 1.0 (§8) has no LEDs; the plate needs no LED provisions for now.

## 5. Target file structure — clean rebuild (decided 2026-07-31)

The v0 sources were **deleted on purpose** (print-validated; everything needed to rebuild is in this doc + [README](README.md)). The rebuild is exactly **three files** — layout data and the cutout module live *inside* `plate.scad` (no separate shared files: with no PCB, only the plate and the assembly consume positions):

```
hardware/3d/
  key_cap.scad   — PRINTABLE: the keycap family cap(w_u, d_u) — WITH the asymmetric cross-bore fix
  plate.scad     — PRINTABLE: N-octave plate (octaves param) = key layout + stepped cutouts + M2
                   + PCF8575 bosses + wire channels + bottom chamfers
  assembly.scad  — VISUAL fit-check: includes both + PCF dummy (collisions, clearances)
```

**Pre-flight fixes baked into the rebuild** (details in [README](README.md) Open): per-arm cross bore (official stem 1.23/1.10 + clearances 0.05/0.18 → both slots 1.28 = the print-validated fit, orientation stays free), bottom-edge chamfers vs elephant foot, pitch set to 18.5 (§7 — parametric, revisit after build 1.0).

## 6. Enclosure vision (context the plate must fit into)

Two shells, M2 sandwich:

- **Top shell** — eventually *absorbs the plate* (the plate is the keyboard region of the top shell) + openings/mounts for: **display (screwed — ST7789 170×320)**, speaker, 2× EC11 encoders, joystick.
- **Bottom shell** — carries the main board: **perfboard (placa perforada) screwed to the enclosure**. No custom PCB this iteration; keyboard = switches hand-wired to the PCF8575, the plate routes the wires (channels).

**Iteration path: start with `plate.scad` + `key_cap.scad` alone, integrate the rest incrementally** (PCF mount → wire channels → display/speaker/encoders/joystick → shell merge).
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

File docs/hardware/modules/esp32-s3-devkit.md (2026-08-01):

# Waveshare ESP32-S3-DEV-KIT-N32R16V

The main board / MCU — runs the firmware and drives every peripheral.

| | |
| --- | --- |
| **Role** | Microcontroller (main board) |
| **Variant on hand** | Waveshare ESP32-S3-DEV-KIT-**N32R16V** (ESP32-S3-WROOM-2, 32 MB OPI flash, 16 MB OPI PSRAM) |
| **Interface** | USB-C (CH343 UART + native USB), GPIO; pin-compatible with ESP32-S3-DevKitC-1 |
| **Operating voltage** | 3.3 V logic (USB-C 5 V in) |
| **Size** | 63.3 × 25.4 mm (DevKitC-1 form factor) |
| **Current draw** | TBD (measure on the bench) |
| **Source** | Waveshare |
| **Price** | — |
| **Quantity** | 1 |

## Datasheets & references

- Product page: https://www.waveshare.com/esp32-s3-dev-kit-n8r8.htm — ⚠️ N8R8 variant page (same board, different flash/PSRAM; Waveshare has no dedicated N32R16V page)
- Waveshare docs (schematic in Resources): https://docs.waveshare.com/ESP32-S3-DEV-KIT-N8R8 — ⚠️ N8R8 variant docs (same board, different flash/PSRAM)
- Pinout (CircuitState): https://www.circuitstate.com/pinouts/waveshare-esp32-s3-dev-kit-nxr8-wi-fi-development-board-pinout-diagram-arduino-reference/
- ESP32-S3-WROOM-1 module: https://www.espressif.com/sites/default/files/documentation/esp32-s3-wroom-1_wroom-1u_datasheet_en.pdf
- ESP32-S3 chip: https://www.espressif.com/sites/default/files/documentation/esp32-s3_datasheet_en.pdf

## Photos

| Front | Back |
| --- | --- |
| ESP32-S3-DEV-KIT front | ESP32-S3-DEV-KIT back |

> Source / credit: [Waveshare](https://www.waveshare.com/esp32-s3-dev-kit-n8r8.htm)

## Pinout

Waveshare ESP32-S3-DEV-KIT-NxR8 pinout — CircuitState Electronics

> Source / credit: [CircuitState Electronics — Waveshare ESP32-S3-DEV-KIT-NxR8 pinout & Arduino reference](https://www.circuitstate.com/pinouts/waveshare-esp32-s3-dev-kit-nxr8-wi-fi-development-board-pinout-diagram-arduino-reference/)
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

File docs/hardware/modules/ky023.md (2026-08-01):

# KY-023 — Dual Axis Joystick

| | |
| --- | --- |
| **Role** | Analog thumbstick — menu navigation / expression / pitch bend |
| **Interface** | 2× analog ADC + 1 digital GPIO |
| **Supply** | 3.3 V ⚠️ (labeled "5V" but the VRx/VRy outputs scale with VCC — powering from 5V damages the ESP32-S3 ADC) |
| **On hand** | 1 |

## Pinout

| Pin | Signal | Description |
| --- | --- | --- |
| GND | GND | |
| +5V | VCC | Connect to **3V3**, not 5V |
| VRx | ADC | X-axis potentiometer |
| VRy | ADC | Y-axis potentiometer |
| SW | Digital | Built-in button (active low, internal pull-up) |

## Wiring

Wiring → [../wiring.md](../wiring.md#ky-023--analog-joystick-) — connections live only there (single source).

## ADC values

The ESP32-S3 uses a 12-bit ADC (0–4095). The center is **not exactly 2048** — the ADC has known non-linearity and the potentiometer is not precision-grade. On this module the resting values sit around **1860–1900** for both axes. Use auto-calibration at startup (see sketch 12).
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

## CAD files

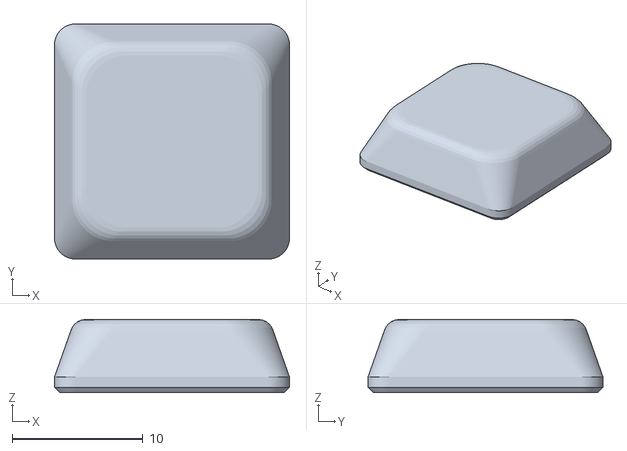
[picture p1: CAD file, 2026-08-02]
hardware/3d/keyboard/stl/key_cap-sharp1.stl
18.0 x 18.0 x 5.60

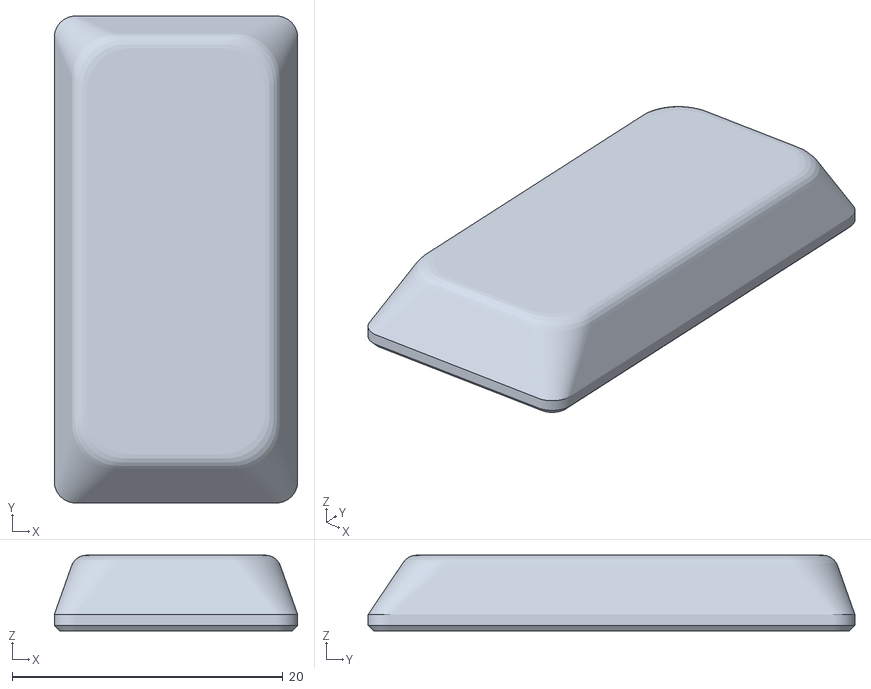
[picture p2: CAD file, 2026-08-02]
hardware/3d/keyboard/stl/key_cap-natural.stl
18.0 x 36.0 x 5.60

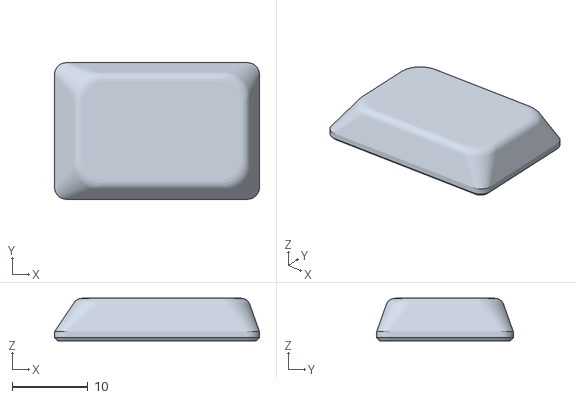
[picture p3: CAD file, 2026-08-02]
hardware/3d/keyboard/stl/key_cap-sharp15.stl
27.0 x 18.0 x 5.60

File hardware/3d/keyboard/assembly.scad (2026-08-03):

// assembly.scad — VISUAL fit check: plate + caps + under-plate ghosts.
// Spec: hardware/3d/keyboard/octaves-plan.md §5 (file structure) / §8 (v1.0 scope).
// Not printable — export STLs from plate.scad and key_cap.scad. This file
// composes them: caps float cap_float above the plate (switch stem height, §7)
// plus the ghost visualizations DEFINED in plate.scad (parametric KS-33 /
// PCF board / right-angle I2C header — fast, and the KS-33 one is the Silent
// we build with). Opt-in vendor meshes (../vendor/, see vendor/README.md)
// overlay the real geometry for high-fidelity checks: the PCF mesh carries
// the true component detail (it caught the SSOP corner), the switch mesh is
// the STANDARD KS-33 — not the Silent — so visual reference only.

use <plate.scad>
use <key_cap.scad>

/* [View] */
show_plate = true;
show_caps = true;
// parametric KS-33 ghosts seated in every cutout (D#/F# rotated per key_rot)
show_switches = false;
// ghost PCF8575 board hanging at standoff height
show_pcf = false;
// ghost right-angle I2C header (5-pin column, tails north over the tab)
show_header = false;
// keys pressed for a quick travel sanity view (0 = none), e.g. 1 presses C;
// range covers the full 24-key final keybed at octaves = 2
pressed_key = 0; // [0:24]

/* [View — vendor meshes (opt-in, slower)] */
// real PCF8575 module mesh (true component detail)
show_pcf_mesh = false;
// real switch mesh — ⚠️ STANDARD KS-33, not the Silent; visual only
show_switch_mesh = false;

/* [Colors — OP-1 × HiChord mood, preview only] */
plate_color = "#37474f";
natural_color = "#eceff1";
sharp_color = "#455a64";

/* [Hidden] */
$fn = $preview ? 32 : 64;
// switch stem height above the plate top (§7 assembly value)
cap_float = 2.0;
// KS-33 total travel
travel = 3.0;

keys = layout_keys(plate_octaves());
echo(str("assembly: ", len(keys), " keys · plate top z=", plate_thick(), " · caps at z=", plate_thick() + cap_float));

// key_dir() (touch direction per key) comes from plate.scad, defined beside
// key_rot() so the per-key identity switches stay with the layout table

if (show_plate) color(plate_color) plate();

if (show_caps)
  for (i = [0 : len(keys) - 1]) {
    k = keys[i];
    z = plate_thick() + cap_float - (i + 1 == pressed_key ? travel : 0);
    color(k[3] == 2 ? natural_color : sharp_color)
      translate([key_x(k), key_y(k), z])
        cap(k[2], k[3], key_dir(k));
  }

if (show_switches) switch_ghosts();
if (show_pcf) pcf_ghosts();
if (show_header) pcf_header_ghosts();
if (show_pcf_mesh) pcf_mesh_ghosts();
if (show_switch_mesh) switch_mesh_ghosts();

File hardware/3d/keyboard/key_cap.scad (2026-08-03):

// key_cap.scad — OP-1-style directional keycap family for the Gateron KS-33 (MX stem).
// Spec: hardware/3d/keyboard/octaves-plan.md §7 (cap params — the single source of values);
// stem measurements: docs/hardware/modules/gateron-ks-33.md (official drawing + vernier).
// v1.0 family (12 caps): 7× natural 1u×2u · 4× sharp 1.5u×1u · 1× G# 1u×1u.
//
// Profile — DIRECTIONAL, OEM-style (decided 2026-08-01): the deep bevel marks
// the touch side, per key: naturals SOUTH (front) · C#/F# WEST · D#/A# EAST ·
// G# ALL sides (under test — fallback: rest value). Other sides get the light
// bevel. Design values sit on a 0.4 mm grid (2026-08-01 polish); FIT values
// (mount/bore) are calibrated or official — NEVER snapped to the grid.
//
// Cross bore — per-arm. Official Gateron LP drawing (vernier-confirmed): stem
// cross 4.00±0.05, arms 1.10±0.04 vertical / 1.23±0.04 horizontal, collar
// ø5.70±0.05, tower 2.95. Slots default to 1.28 × 1.28 — the PRINT-VALIDATED
// geometry (PLA/PETG, 0.2 & 0.4 nozzles): thin 1.10 + 0.18, wide 1.23 + 0.05.
// Equal slots → cap orientation stays free (no LED-north constraint). Bore
// length 4.1 (= span + 0.1) and R0.3 inner-corner fillets follow the official
// Cherry keycap spec; the Cherry 1.17 symmetric slot is for injection POM/ABS
// (interference grip) — too tight for stiff FDM PLA, do not adopt it. Cherry
// socket depths (3.6/3.8 min) are full-height MX — the KS-33 tower is only
// 2.95, so socket_depth stays 2.8.
//
// Print orientation: TOP FACE DOWN — cosmetic face on the (textured) build
// plate; walls, post and cavity ceiling all build support-free. bottom_chamfer
// (skirt + post foot) covers the skirt-down orientation too, and doubles as a
// lead-in over the switch collar.

/* [Part] */
// what to render/export: family = one of each PRINTED part. sharp15 covers both
// C#/F# and (rotated 180° at install) D#/A# — the N/S-symmetric profile makes
// W/E the same piece; assembly.scad still previews the "E" orientation via dir.
part = "family"; // [family, natural, sharp15, sharp1]
// split the post through the wide slot so the cross flexes instead of cracking
// (untested print experiment — off = the print-validated geometry)
split_post = false;

/* [Render] */
// cutaway through the cross bore
section = false;

// ---- everything below is FROZEN (official values, print-validated fits or
// closed design decisions — dates on each group). Not Customizer knobs. ----
/* [Hidden] */
$fn = $preview ? 32 : 96;
eps = 0.01;

// ---- size ----
// cap unit (mm) — fixed by the design; pitch = unit + gap lives in plate.scad
unit_mm = 18;
cap_height = 5.6;

// ---- directional profile (0.4 grid, closed 2026-08-01) ----
// deep bevel = the touch side (naturals S, C#/F# W, D#/A# E) — sharps stay
// N/S symmetric ("centred"), only left/right varies per key (closed 2026-08-01)
bevel_main = 2.4;
// light bevel on the remaining sides; G# (1u×1u) uses this on ALL sides
bevel_rest = 1.2;

// ---- profile — tuned look (§7) ----
// vertical rim before the bevel starts
base_rim_height = 1.2;
// circular roundover into the flat top (all four edges); MUST stay < top_thickness
top_edge_round = 1.2;
base_corner_r = 1.6;
// = 2× base_corner_r
top_corner_r = 3.2;

// ---- shell — hollow, open bottom ----
wall_thickness = 1.2;
// cavity ceiling; must exceed top_edge_round (or the roundover eats the ceiling edge)
top_thickness = 1.6;
// cavity corner radius (= base_corner_r, matching the outer look; corners get
// slightly thicker than the flats — fine, adds strength)
cavity_corner_r = 1.6;
// 45° chamfer on the bottom edges of skirt (outer + inner) AND post foot (outer)
// — counters elephant foot if printed skirt-down; min ≈ first layer (0.2),
// recommended 0.3–0.5 → 0.4 on the grid
bottom_chamfer = 0.4;

// ---- mount — official Gateron LP drawing, vernier-confirmed — NOT on the 0.4 grid ----
// cap post ø (official cap spec 5.5±0.05; switch collar is ø5.70)
post_diameter = 5.5;
// stem cross envelope 4.00±0.05
cross_span = 4.0;
// stem arm widths ±0.04: wide arm horizontal (LED-window side)
cross_arm_wide = 1.23;
cross_arm_thin = 1.10;
// KS-33 mount tower is 2.95 — socket must stay shorter (NOT Cherry's 3.6/3.8)
socket_depth = 2.8;

// ---- print fit — calibrated, NOT on the 0.4 grid ----
// thin arm clearance — print-validated 0.18 FDM (0.2 & 0.4 nozzles, PLA/PETG); resin 0.05
stem_clearance = 0.18;
// wide arm clearance — 0.05 → slot 1.28 = the print-validated grip fit;
// unequal slots would force LED-north orientation (echo warns)
stem_clearance_wide = 0.05;
// bore length clearance → 4.1 total (official Cherry cap spec 4.1+0.05)
span_clearance = 0.1;
// inner-corner fillet of the cross (official cap spec; avoids FDM corner cracks)
cross_corner_r = 0.3;
// 45° flared lead-in at the bore mouth (0.2 = the official cap spec value)
mouth_flare = 0.2;

// ---- derived ----
cavity_top = cap_height - top_thickness;
bevel_end = cap_height - top_edge_round;
slot_wide = cross_arm_wide + stem_clearance_wide; // x-slot width (in y)
slot_thin = cross_arm_thin + stem_clearance;      // y-slot width (in x)
bore_span = cross_span + span_clearance;          // slot length, both axes

// per-key insets [N, E, S, W] from the touch direction;
// "ALL" (G#) = the light bevel all around — no deep side (decided 2026-08-01)
function cap_insets(dir) =
  dir == "S"   ? [bevel_rest, bevel_rest, bevel_main, bevel_rest] :
  dir == "W"   ? [bevel_rest, bevel_rest, bevel_rest, bevel_main] :
  dir == "E"   ? [bevel_rest, bevel_main, bevel_rest, bevel_rest] :
                 [bevel_rest, bevel_rest, bevel_rest, bevel_rest];

bore_wall = post_diameter/2 - sqrt(pow(bore_span/2, 2) + pow(max(slot_wide, slot_thin)/2, 2));
echo(str("slots: wide(horiz) ", slot_wide, " · thin(vert) ", slot_thin,
         slot_wide == slot_thin ? " — EQUAL (orientation-free, = validated v0)" : " — ASYMMETRIC (mount LED-north!)"));
echo(str("bore ", bore_span, " long · post wall at slot ends ", bore_wall,
         " mm · bevels main/rest ", bevel_main, "/", bevel_rest));
assert(bore_wall > 0.4, "cross bore leaves too little post wall");
assert(cavity_top < bevel_end, "cavity must end below the top roundover: top_thickness must exceed top_edge_round");
assert(socket_depth < cavity_top, "cross bore would pierce the cavity ceiling");
assert(mouth_flare < socket_depth, "flare deeper than the socket");
assert(bottom_chamfer < base_rim_height, "chamfer taller than the rim");
assert(2 * bottom_chamfer < wall_thickness, "chamfers meet inside the wall");

module rsq(w, d, r) offset(r = r) square([w - 2*r, d - 2*r], center = true);

// rectangle with independent per-side insets (from the w×d centred footprint)
module arect(w, d, ins, r) {
  xw = w - ins[1] - ins[3];
  yd = d - ins[0] - ins[2];
  translate([(ins[3] - ins[1])/2, (ins[2] - ins[0])/2]) rsq(xw, yd, r);
}

// bottom chamfer → vertical rim → per-side bevel → roundover on all edges.
module cap_outer(w, d, ins) {
  hull() {
    linear_extrude(eps) offset(delta = -bottom_chamfer) rsq(w, d, base_corner_r);
    translate([0, 0, bottom_chamfer])
      linear_extrude(base_rim_height - bottom_chamfer) rsq(w, d, base_corner_r);
    for (a = [0:15:90]) {
      ro = top_edge_round * (1 - cos(a));
      translate([0, 0, bevel_end + top_edge_round * sin(a) - eps])
        linear_extrude(eps)
          arect(w, d, [for (i = ins) i + ro], top_corner_r);
    }
  }
}

// cavity follows the same per-side geometry, scaled to where it tops out;
// the mouth flares out by bottom_chamfer (inner anti-elephant-foot chamfer)
module cap_cavity(w, d, ins) {
  k = (cavity_top - base_rim_height) / (bevel_end - base_rim_height);
  union() {
    // mouth chamfer — separate hull, or the convex hull would smear it into a taper
    hull() {
      translate([0, 0, -eps]) linear_extrude(eps)
        offset(delta = bottom_chamfer) rsq(w - 2*wall_thickness, d - 2*wall_thickness, cavity_corner_r);
      translate([0, 0, bottom_chamfer]) linear_extrude(eps)
        rsq(w - 2*wall_thickness, d - 2*wall_thickness, cavity_corner_r);
    }
    hull() {
      translate([0, 0, -eps]) linear_extrude(base_rim_height + eps)
        rsq(w - 2*wall_thickness, d - 2*wall_thickness, cavity_corner_r);
      translate([0, 0, cavity_top - eps]) linear_extrude(eps)
        arect(w - 2*wall_thickness, d - 2*wall_thickness, [for (i = ins) i*k], cavity_corner_r);
    }
  }
}

// "+" profile with R0.3 fillets in the four inner corners (offset-closing)
module cross_profile() {
  offset(r = -cross_corner_r) offset(r = cross_corner_r) union() {
    square([bore_span, slot_wide], center = true); // wide arm horizontal
    square([slot_thin, bore_span], center = true); // thin arm vertical
  }
}
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

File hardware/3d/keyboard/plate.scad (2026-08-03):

// plate.scad — N-octave keyboard plate for Gateron KS-33 low-profile switches.
// Spec: hardware/3d/keyboard/octaves-plan.md — §2 calibrated values (do NOT re-derive),
// §7 layout/cutout snapshots, §8 v1.0 scope (octaves = 1, 12 keys C–B).
// Batch-2 scope (2026-08-02): the plate prints as a COMPLETE keyboard module —
// PCF8575 VERTICAL in the D#↔F# bay (the pillar-free spot), M2×5 bosses:
// south (mid) pair in the naturals↔sharps web, north (header) pair on a
// derived back tab (module dims: docs/hardware/modules/pcf8575.md §Mechanical).
// Module mounts component side + right-angle I2C header toward the plate,
// solder face out (tails point outward, joints accessible).
// ASSEMBLY RULE: D# switch turns -90° (pins WEST) and F# +90° (pins EAST) so
// their pins point away from the board (pins sit in the switch's south half).
// Wire channels: routed 1:1 from hardware/3d/keyboard/wiring-plan.svg (FROZEN
// 2026-08-03) — signal lanes in the naturals↔sharps web at the EXACT PCF pin
// heights (Δ2.54, dead-straight entry into every pin, both rows), pin map
// C→P04 D→P05 E→P06 F→P07 C#→P02 D#→P01 · A→P10 B→P11 A#→P12 G#→P13 F#→P15
// G→P17 (free P00·P03·P14·P16; A#/G# switch pins inverted: signal = east
// pin). GND = two chains per octave (west: row GND → D# → high C#–D# passage
// → Z-descent in the C#–C web → C; east: row GND → F# → S-drop in the F#–G#
// web → G#/A# pin-height passages → side-drop column → B) + ONE gutter
// across the front apron whose ends curl 90° north into the C/B GND pins
// and which reaches every other natural's GND pin through a spur at the pin
// x — double width at D–A (the wire enters AND leaves, two cables side by
// side, a T with both 90° sweeps). Two under-board runs: G→P17 squeezed
// between the south bosses, F→P07 climbing straight into its pin after
// crossing the E pocket at the pillar limit. Every direction change is a
// swept chan_bend arc (r 1.2 — the 1.4 wire takes it). D#→P01 and F#→P15
// are pure air; under pockets and over the board the wire flies free.
// Feet (dev aid, `feet` flag): the plate stands flat with switches + PCF +
// header mounted — turn off at shell-merge time.
// Ghosts: the visualization modules (parametric KS-33 / PCF board / I2C
// header + opt-in vendor-mesh imports) are DEFINED here (they read this
// file's params) but COMPOSED in assembly.scad — that's where the show_*
// flags live. This file renders the printable plate only.
// No M2 plate↔shell screws yet — batch 3.
// Print orientation: modeled keyboard-face UP; flip 180° about Y in the slicer
// (REQUIRED: each cutout step then rests on solid material — no bridging).
// Edge chamfers are on BOTH faces, so either face down avoids elephant foot.

/* [Layout] */
octaves = 1; // [1:4]

/* [Print fit] */
// cutout kerf — print-validated (PLA/PETG, 0.2 & 0.4 nozzles): 0; + looser / − tighter
kerf = 0.0;

/* [Feet] */
// print the feet (bench aid + integration-deck bosses; turn off at shell-merge time)
feet = true;

// ---- everything below is FROZEN (print-validated or decided — dates on each
// group). Not Customizer knobs: change only with a documented re-decision. ----
/* [Hidden] */
$fn = $preview ? 32 : 96;
eps = 0.01;

// ---- cap grid (frozen 2026-08-01) ----
// cap unit (mm) — fixed by the cap design
cap_1u = 18;
// pitch = cap_1u + cap_gap (18.8: 0.8 = 2×0.4 grid, backed by v0's
// print-validated 1.0 gap; 0.5 was never printed side-by-side)
cap_gap = 0.8;
pitch = cap_1u + cap_gap;

// ---- plate (frozen 2026-08-01/02) ----
// = shelf 1.2 + pocket 1.2
thick = 2.4;
// plate margin beyond the cap bounding box (2026-08-01: 1.6 = 2× cap_gap, 0.4 grid)
margin = 1.6;
// plate corner radius — cap base_corner_r 1.6 + margin 1.6 = 3.2: the plate edge
// runs concentric with the corner cap's rounded corner
prad = 3.2;
// edge chamfer on BOTH faces — counters elephant foot whichever face prints down;
// ~0.3 ≈ first layer height + margin (see docs/hardware/fdm-tolerances.md)
edge_chamfer = 0.3;
// concave fillet where the back tab meets the plate edge (2D closing offset)
tab_fillet = 2.4;

// ---- KS-33 cutout (calibrated §2, do NOT re-derive) ----
// clip cutout (top, KS-33 standard)
hole_t = 14.0;
// body pocket (bottom) — INDEPENDENT value, never derive as hole_t + shelf
hole_b = 15.2;
// clip shelf thickness (plate-thickness spec)
shelf = 1.2;
hole_r = 0.5;
// elephant-foot relief on the TOP-face hole rim (the face the print starts
// on in the flipped orientation): a 45° chamfer, hole_chamfer wide AND tall.
// fdm-tolerances prescribes 0.3, but the flange seat caps the lateral relief:
// the Silent flange is 14.5 on a 14.0 hole → 0.25/side of seat, so 0.15
// (keeping 0.10/side) is the max. This 45° × 0.15 relief is what batch 2
// printed. 0 = the exact print-validated geometry (slicer compensation)
hole_chamfer = 0.15;
// Silent flange width (vernier, gateron-ks-33.md) — caps hole_chamfer
ks33_flange_silent = 14.5;
// 45° edge break on the pocket rims of the BOTTOM (channel) face — same
// language as chan_rim; chamfer over fillet (2026-08-03): at 0.3 with 0.2
// layers both print identically, and the whole file speaks 45°. No seat
// constraint on this face (the flange seats on the top face only)
hole_rim = 0.3;

// ---- PCF8575 mount (measured, pcf8575.md §Mechanical; settled 2026-08-02) ----
// board outline (vernier 2026-08-01); dummy/ghost only, bosses anchor on holes
pcf_board_l = 32.1;
pcf_board_w = 21.3;
pcf_board_t = 1.6;
// mounting-hole pitch along the board's long axis (pitch-true PCB drill)
pcf_hole_pitch = 28.3;
// hole-pair spans across the board: corner pair (5-pin-header end) / mid pair
pcf_span_a = 17.0;
pcf_span_b = 6.5;
// module centre Y — vertical module, 24.4 (0.4 grid, moved +0.4 north
// 2026-08-02): both boss-pair root coves land fully on solid web — south
// pair clears the naturals pockets AND the wire channels; north pair clears
// the sharps pockets (all four sides asserted)
pcf_cy = 24.4;
// boss height below the plate — 2.8 (0.4 grid, 2026-08-02): the board sits in
// the pillar-free D#↔F# spot (D#/F# pins rotated away), so the floor is the
// right-angle header body 2.5 (tallest on the component side, > SSOP 2.1)
// + 0.3 air under the tab
pcf_standoff = 2.8;
// M2 self-tap boss OD — 4.4 (0.4 grid) = pilot 1.8 + 1.3 wall (>3 perimeters
// of 0.4). Below the fdm-tolerances ≥2 wall rule, accepted 2026-08-02: tiny
// 5 g board, non-structural; tap gently — self-tap hoop stress splits
// thinner walls, ø4.0 is the absolute floor
pcf_boss_od = 4.4;
pcf_pilot_d = 1.8;
// M2×5 (decided 2026-08-02): 5 − 1.6 board = 3.4 thread + 0.4 tip room —
// pilot pierces 1.0 into the plate web (top face intact; shelf assert guards)
pcf_pilot_depth = 3.8;
// KS-33 under-plate centre pillar ø (gateron-ks-33.md §under-plate) — used
// for the board↔pillar lateral-clearance invariant
ks33_pillar_d = 4.9;
// hole-pattern centre X of the vendor STL frame (measured in FreeCAD) — only
// used by the opt-in mesh ghost (assembly.scad → show_pcf_mesh)
pcf_stl_pattern_cx = 15.25;

// ---- KS-33 dims (doc-exact, gateron-ks-33.md) — routing/asserts + ghost ----
// flange footprint (rests on the plate top) / below-flange body (through-plate)
ks33_flange = 15.0;
ks33_body = 13.9;
// body height below the flange — base ends 0.1 proud of the plate bottom
ks33_below = 2.5;
// housing above the plate top (5.2 total − 2.5 below the flange)
ks33_housing_h = 2.7;
// keycap-mount tower: footprint + official height (its top = cap socket ref)
ks33_stem_w = 6.4;
ks33_stem_d = 6.2;
ks33_tower_h = 2.95;
// under-plate drops below the housing base: pillar tip → 3.4 / pin tips → 2.7
// below the plate bottom (doc-exact, the numbers the mount design leans on)
ks33_pillar_h = 3.3;
ks33_pin_drop = 2.6;
// contact-pin positions from the switch centre (STEP slice — both SOUTH half)
ks33_pin_pos = [[-4.4, -4.7], [2.6, -5.75]];
// vendor STL frame (ks33-switch.stl): x centred at 60, z0 = pillar tip —
// the flange underside is derived from the doc dims so a re-measure keeps
// the mesh ghost seated right (frame notes: vendor/README.md). Only used
// by the opt-in mesh ghost (assembly.scad → show_switch_mesh)
ks33_stl_cx = 60;
ks33_stl_flange_z = ks33_below + ks33_pillar_h;

// ---- I2C header (2.54 right-angle male on the 5-pin column) — the pin
// ladder (hdr_pitch) also derives the routing lanes; rest is ghost/stack ----
hdr_pitch = 2.54;
hdr_pins = 5; // [1:10]
// pin cross-section (0.64 sq standard)
hdr_pin_sq = 0.64;
// plastic body height/depth (2.5 sq profile standard) = the standoff floor
hdr_body = 2.5;
// horizontal pin length beyond the plastic body
hdr_horiz = 6.0;
// tail protrusion past the solder (bare) face — sets the under-plate
// maximum. 1.0 = TRIMMED after soldering (2026-08-03, was 2.0 uncut: clip
// the tails flush with cutters once the header is soldered)
hdr_tail = 1.0;
// column position (pcf8575.md): holes 2.3 from the 5-pin edge, column 1.2 in
pcf_hole_edge = 2.3;
pcf_hdr_inset = 1.2;
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

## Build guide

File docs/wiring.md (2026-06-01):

# Pocket Groovebox — Wiring

> 🚧 **Draft — provisional, pending bench tests.** Pin choices may change.

How the modules connect to the ESP32-S3. This doc is **only the connection structure** — each module's own specs and pinout live in [modules/](modules/). Pin choices follow the verified-safe 3.3 V GPIO pool documented in [modules/esp32-s3-devkit.md](modules/esp32-s3-devkit.md#gpio-usage-n32r16v).

## Connection overview

```mermaid
flowchart LR
    MCU["ESP32-S3"]
    MCU -->|"I2S — BCK 5 / DIN 6 / LRCK 7"| DAC["PCM5102 DAC"]
    MCU -->|"SPI — SCL 9 / SDA 10 / RES 11 / DC 12 / CS 13 / BLK 14"| TFT["ST7789 1.9in 170x320"]
    DAC -->|"line out"| HP["Headphone jack"]
    DAC -->|"line out"| AMP["PAM8403"]
    AMP --> SPK["Speaker"]
```

## Connections

### PCM5102 — I2S DAC

| ESP32-S3 | PCM5102 |
| --- | --- |
| GPIO5 | BCK (bit clock) |
| GPIO6 | DIN (data) |
| GPIO7 | LRCK / WS |
| 3V3 | VIN / VCC |
| GND | GND |

DAC and display both live on the **left header** — the only side with enough usable GPIOs (the right header has just 3: 1/2/21). BCK·DIN·LCK = GPIO **5·6·7**, same order as the module's header so the wires run straight across; SCK ties to GND. 3V3 and GND are both on the left header, so no power wire has to cross.

Module config: tie **SCK → GND** (internal PLL); set the FLT / DEMP / FMT / XSMT jumpers per the breakout (⚠️ our board's H/L labels are inverted — see [modules/pcm5102.md](modules/pcm5102.md#config-jumpers-solder-pads-back-of-board)).

### ST7789 — 1.9" 170×320 SPI display

| ESP32-S3 | ST7789 |
| --- | --- |
| GPIO9 | SCL / SCLK |
| GPIO10 | SDA / MOSI |
| GPIO11 | RES / RST |
| GPIO12 | DC |
| GPIO13 | CS |
| GPIO14 | BLK (backlight) |
| 3V3 | VCC |
| GND | GND |

GPIO **9–14**, assigned in the screen's own header order (SCL·SDA·RES·DC·CS·BLK) so the wires run straight across. SPI is fully remappable on the S3, so the order is a free choice. DAC sits just above at 5/6/7.

Write-only — no MISO. The 170×320 panel needs a driver offset (Arduino_GFX / TFT_eSPI).

### Still to assign

Keyboard (13 keys) and 2× EC11 encoders — pins TBD. Still free: left header GPIO **4, 8, 15, 16, 17, 18** plus right header **1, 2, 21**. Note GPIO9 is used by the display (SCL), so the I2C default of 8/9 would need remapping if an expander is added.

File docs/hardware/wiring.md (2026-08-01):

# Pocket Groovebox — Wiring

> 🚧 **Draft — pin choices may change during bench tests.**

How the modules connect to the ESP32-S3. This doc is **only the connection structure** — each module's own specs and pinout live in [modules/](modules/). Pin choices follow the verified-safe 3.3 V GPIO pool documented in [modules/esp32-s3-devkit.md](modules/esp32-s3-devkit.md#gpio-usage-n32r16v).

**Status:**
- ✅ PCM5102 DAC, ST7789 display, PAM8403 amp — verified and wired
- ✅ EC11 encoders and joystick — on hand, wiring defined
- 🚧 Keyboard (24 keys via PCF8575 ×2) — wiring defined; V1 uses OP-1-style flat caps directly on switches (no lever), keycap + plate CAD in progress. **Build 1.0** = 12 keys (one octave C–B) on a single PCF8575 (0x20)
- ⏸ SK6812 MINI-E LEDs — wiring defined but **deferred** (needs a PCB; not in build 1.0)

## Connection overview

```mermaid
flowchart LR
    MCU["ESP32-S3"]
    MCU -->|"I2S — BCK 5 / DIN 6 / LRCK 7"| DAC["PCM5102 DAC"]
    MCU -->|"SPI — SCL 9 / SDA 10 / RES 11 / DC 12 / CS 13 / BLK 14"| TFT["ST7789 1.9in 170×320"]
    MCU -->|"I2C — SDA 4 / SCL 8 / INT 15 (wired-OR)"| EXP1["PCF8575 #1 (0x20)"]
    MCU -->|"I2C — SDA 4 / SCL 8 / INT 15 (wired-OR)"| EXP2["PCF8575 #2 (0x21)"]
    EXP1 -->|"P00–P15"| KEYS1["Keys C3–D#4 (16 keys)"]
    EXP2 -->|"P00–P07"| KEYS2["Keys E4–B4 (8 keys)"]
    MCU -->|"GPIO 39/40/41/42 (CLK/DT) + 16/17 (SW)"| ENC["2× EC11 encoders"]
    MCU -->|"GPIO 18 → 74AHCT125"| LED["SK6812 MINI-E × 24 (deferred)"]
    MCU -->|"ADC GPIO 1/2 + GPIO 21"| JOY["Joystick (analog + button)"]
    DAC -->|"line out"| HP["Headphone jack"]
    DAC -->|"LROUT/ROUT"| AMP["PAM8403"]
    AMP -->|"BTL"| SPK["Speaker"]
```

## Connections

### PCM5102 — I2S DAC

| ESP32-S3 | PCM5102 |
| --- | --- |
| GPIO5 | BCK (bit clock) |
| GPIO6 | DIN (data) |
| GPIO7 | LRCK / WS |
| 3V3 | VIN / VCC |
| GND | GND |

DAC and display both live on the **left header** — the only side with enough usable GPIOs (the right header has just 3: 1/2/21). BCK·DIN·LCK = GPIO **5·6·7**, same order as the module's header so the wires run straight across; SCK ties to GND. 3V3 and GND are both on the left header, so no power wire has to cross.

Module config: tie **SCK → GND** (internal PLL); set the FLT / DEMP / FMT / XSMT jumpers per the breakout (⚠️ our board's H/L labels are inverted — see [modules/pcm5102.md](modules/pcm5102.md#config-jumpers-solder-pads-back-of-board)).

### PAM8403 — speaker amp

| From | PAM8403 (QA03) |
| --- | --- |
| PCM5102 LROUT | L (audio in) |
| PCM5102 ROUT | R (audio in) |
| PCM5102 AGND | GND (audio in) |
| 5V / VBUS | 5V (+) |
| GND | GND (−) |
| Speaker (4 Ω 3 W, [modules/speaker.md](modules/speaker.md)) | across **L+ / L−** (BTL) |

The amp's input is the **analog line out** of the PCM5102 (LROUT/ROUT), not the I2S signal. **Don't skip `AGND → amp GND`** — the signal ground is as important as the supply ground; without it the amp floats and screams noise at full volume regardless of the digital level (see [modules/pam8403.md](modules/pam8403.md#notes--gotchas)). Output is **BTL** — the speaker floats between L+ and L−; **never tie any `OUT` pad to GND** (it shorts the bridge and can kill the chip), and never connect headphones to the amp (those come off the DAC). Powered from the devkit **5 V / VBUS** pin so the amp, DAC AGND, and ESP32 share one ground. Fixed gain (no pot) — set level via the sketch's `AMPLITUDE`. Pinout and gotchas: [modules/pam8403.md](modules/pam8403.md).

### ST7789 — 1.9" 170×320 SPI display

| ESP32-S3 | ST7789 |
| --- | --- |
| GPIO9 | SCL / SCLK |
| GPIO10 | SDA / MOSI |
| GPIO11 | RES / RST |
| GPIO12 | DC |
| GPIO13 | CS |
| GPIO14 | BLK (backlight) |
| 3V3 | VCC |
| GND | GND |

GPIO **9–14**, assigned in the screen's own header order (SCL·SDA·RES·DC·CS·BLK) so the wires run straight across. SPI is fully remappable on the S3, so the order is a free choice. DAC sits just above at 5/6/7.

Write-only — no MISO. The 170×320 panel needs a driver offset (Arduino_GFX / TFT_eSPI).

### PCF8575 — 16-bit I2C I/O expander (keyboard, 2× chips)

Two PCF8575s share the same I2C bus (SDA/SCL) and a single INT line wired open-drain (wired-OR). Any key press on either chip pulls INT low and wakes the ESP32-S3 interrupt handler, which then reads both chips to resolve which key(s) changed.

> **Build 1.0:** only 12 keys (one octave, C–B) wired to a single PCF8575 at 0x20 (P00–P13, same order as chip #1 below). The second chip joins in the full 24-key build.

**Shared I2C connections (both chips):**

| ESP32-S3 | PCF8575 | Notes |
| --- | --- | --- |
| GPIO4 | SDA | 4.7 kΩ pull-up to 3.3 V (one resistor on the bus is enough) |
| GPIO8 | SCL | 4.7 kΩ pull-up to 3.3 V (one resistor on the bus is enough) |
| GPIO15 | INT | 4.7 kΩ pull-up to 3.3 V; both chips' INT pins wire directly to this GPIO (open-drain wired-OR). Defined, not yet exercised — all sketches poll so far |
| 3V3 | VCC | |
| GND | GND | |

**PCF8575 #1 — I2C address 0x20 (A0=A1=A2=GND):**

| PCF8575 pin | Key |
| --- | --- |
| P00 | C3 |
| P01 | C#3 |
| P02 | D3 |
| P03 | D#3 |
| P04 | E3 |
| P05 | F3 |
| P06 | F#3 |
| P07 | G3 |
| P10 | G#3 |
| P11 | A3 |
| P12 | A#3 |
| P13 | B3 |
| P14 | C4 |
| P15 | C#4 |
| P16 | D4 |
| P17 | D#4 |

**PCF8575 #2 — I2C address 0x21 (A0=3V3, A1=A2=GND):**

| PCF8575 pin | Key |
| --- | --- |
| P00 | E4 |
| P01 | F4 |
| P02 | F#4 |
| P03 | G4 |
| P04 | G#4 |
| P05 | A4 |
| P06 | A#4 |
| P07 | B4 |
| P10–P17 | spare (8) |

Each key is wired between its P-pin and GND. Key pressed = pin reads 0. See [modules/pcf8575.md](modules/pcf8575.md) for pull-up requirements and I2C read protocol.

### EC11 — rotary encoders (×2)

JTAG pins GPIO39–42 are input-only on the ESP32-S3 but usable for encoder CLK/DT (always inputs). This frees all regular GPIOs for outputs and bidirectional use.

| Signal | ESP32-S3 | Notes |
| --- | --- | --- |
| EC11 #1 CLK | GPIO39 | JTAG pin — input-only; enable internal pull-up |
| EC11 #1 DT  | GPIO40 | JTAG pin — input-only; enable internal pull-up |
| EC11 #1 SW  | GPIO16 | regular GPIO; enable internal pull-up |
| EC11 #2 CLK | GPIO41 | JTAG pin — input-only; enable internal pull-up |
| EC11 #2 DT  | GPIO42 | JTAG pin — input-only; enable internal pull-up |
| EC11 #2 SW  | GPIO17 | regular GPIO; enable internal pull-up |

All encoder signals wire encoder pin → ESP32-S3 GPIO; the encoder's common/ground pin ties to GND.

### SK6812 MINI-E — per-key RGB LEDs (×24) — deferred

> ⏸ **Deferred:** the per-key LEDs require the PCB version of the keyboard — build 1.0 (hand-wired) has no LEDs. Wiring below is the target design for the PCB iteration.

One LED per key, driven from a single GPIO via the ESP32-S3 RMT peripheral. A 74AHCT125 level shifter is mandatory (ESP32-S3 outputs 3.3 V; VIH = 3.5 V at 5 V supply — direct connection is out of spec).

| Signal | Connection |
| --- | --- |
| ESP32-S3 GPIO18 | → 74AHCT125 input (OE pin tied LOW) |
| 74AHCT125 output | → 330–500 Ω series resistor → LED #1 DIN |
| LED #1 DOUT | → LED #2 DIN → … (chain of 24) |
| All LED VDD | 5 V (VBUS) |
| All LED GND | GND |

See [modules/sk6812mini-e.md](modules/sk6812mini-e.md) for full timing, power budget, and level-shifter details.

### KY-023 — analog joystick ✅

Role TBD (pitch bend / expression / note selection / menu navigation). Axis pins feed ADC1; right-header GPIOs avoid ADC2 (shares resources with Wi-Fi). See [modules/ky023.md](modules/ky023.md).

| Signal | ESP32-S3 | Notes |
| --- | --- | --- |
| VRx | GPIO2 (ADC1_CH1) | analog |
| VRy | GPIO1 (ADC1_CH0) | analog |
| SW  | GPIO21 | digital input; `INPUT_PULLUP`; 1=idle, 0=pressed |
| VCC | 3V3 | ⚠️ labeled "5V" — connect to 3V3 or the S3's ADC is damaged |
| GND | GND | |

**Orientation:** on the test board the module is rotated 90° CCW (labels facing down). The mount swap and polarity are compensated in software via a single `JOY_MOUNT` knob — see [modules/ky023.md](modules/ky023.md#orientation-and-axis-swap).

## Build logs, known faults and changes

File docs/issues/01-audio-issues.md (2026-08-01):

# 01 — Audio output issues & backlog

Captured while bringing up the playable keyboard sketch ([`sketches/09-audio-notes-gate`](../../sketches/09-audio-notes-gate/09-audio-notes-gate.ino)). The sketch is kept **simple on purpose** — note on/off, polyphony, momentary maj/min chords, volume. No tone-shaping (filters/limiter) lives in it. The items below are real but each belongs to a *separate* fix (a future DSP sketch, or hardware), not this one.

## Known issues

### 1. Low chords sound "bloated" on the speaker
- **Status:** ✅ absorbed into `architecture.md` — the mixer spec (1/MAX_VOICES scaling + tanh soft limiter) covers polyphony level, and the ~150–200 Hz speaker high-pass was migrated there too.
- **Cause:** the 30 mm 4 Ω speaker can't reproduce deep bass; low notes (esp. several at once) over-excurt the cone → flabby/overflowing sound. Confirmed it's **physical**: the same chords are clean on headphones off the PCM5102.
- **Fix later (software, separate DSP sketch):** high-pass the mix (~150–200 Hz, the speaker barely outputs below that anyway), and/or scale amplitude with polyphony so stacking notes doesn't inflate level. A 2-pole high-pass was prototyped and removed to keep this sketch simple.
- **Fix later (hardware):** a bigger speaker / one with an enclosure (see hardware eval below).

### 2. Speaker hisses when nothing is playing
- **Status:** 🔧 pending (hardware, unowned).
- **Cause:** the PAM8403 (QA03) is a cheap BTL class-D amp with an always-present noise floor; USB 5 V is noisy and class-D barely rejects it. See [modules/pam8403.md](../hardware/modules/pam8403.md).
- **Fix later (hardware):** **100 µF + 0.1 µF decoupling cap** across the amp `5V`/`GND` (most effective; already on the shopping list), short input wires away from I2S/USB. Eventually an amp with a **shutdown pin** to mute it when idle.

### 3. Headphones are much quieter than the speaker
- **Status:** 🔧 pending (hardware, unowned).
- **Cause:** the headphone jack gets the **raw line level** from the PCM5102, while the speaker gets that **+ the amp's ~24 dB gain**. `masterAmp` is tuned low (~320) for the loud amplified speaker, so on headphones it's faint. Two different gain stages, one digital level.
- **Consolidating both (options, for a later iteration):**
  - **Software:** detect headphone insertion (needs a jack with a detect switch wired to a GPIO) and bump the digital level when plugged; keep separate "speaker level" vs "headphone level" presets.
  - **Hardware:** a small headphone amp on the line-out, or accept that headphone listening just needs the volume turned up (the slider already allows it).

### 4. Speaker keeps playing when headphones are plugged in
- **Status:** 🔧 pending (hardware, unowned).
- **Cause:** the PCM5102 module's 3.5 mm jack does **not** cut the line-out feeding the amp, and we don't detect insertion, so both sound at once.
- **Fix later (hardware):** use a headphone jack with a **switched (detect) contact** → either break the amp input mechanically, or wire the switch to a GPIO and **mute the amp** (needs an amp with a shutdown pin, or mute via the DAC's XSMT / a software gate on the speaker path). Pure-software muting isn't possible without that insertion signal.

### 5. Physical master volume
- **Want:** a real knob instead of only the on-screen/`V0..9` digital volume.
- **Fix later:** the plan already includes **2× EC11 encoders** ([hardware.md](../hardware/README.md)) — assign one to master volume in firmware (read encoder → set `masterAmp`). Alternatively a real potentiometer, but a pot on the line-out attenuates before the amp and adds noise; an encoder driving the digital level is cleaner. (A physical knob also lets headphone vs speaker levels be matched live, helping issue #3.)

## Hardware eval — better amp / speaker?

> **Status:** 🔧 pending (hardware, unowned).

- **Speaker is the bigger limitation.** The 30 mm driver is the main reason low chords bloat and there's no real bass. A larger driver (≈40–50 mm) or a small full-range **with an enclosure/baffle** would improve low-mid handling and reduce the bloat far more than any software filter. Highest-impact upgrade for sound quality.
- **Amp is acceptable.** The PAM8403 delivers enough power (2×3 W); its weak point is the **idle hiss** (issue #2) — mostly fixed by the decoupling cap. If we respin: consider an amp with a **shutdown/mute pin** (e.g. PAM8302A mono) so issues #2 and #4 get a clean hardware mute, or the **MAX98357A** (I2S amp, lower noise — but it's speaker-only, so headphones would still come off the PCM5102).
- **Verdict:** keep the PAM8403 for now (+ decoupling cap + later a shutdown-capable amp); **prioritize a better/larger speaker** for the next hardware order.

> Historical note: a proposal to split sketch 09 into focused sketches was dropped when Phase 2 closed.

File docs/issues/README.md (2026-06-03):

# Issues & backlog

Known problems and deferred work, one numbered file per topic. Each file lists the issue, its cause, and where the fix belongs (software / hardware / a future sketch). Add new topics with the next number.

| # | Topic | File |
| --- | --- | --- |
| 01 | Audio output (speaker bloat, hiss, headphone level/routing, master volume, amp/speaker eval) | [01-audio-issues.md](01-audio-issues.md) |

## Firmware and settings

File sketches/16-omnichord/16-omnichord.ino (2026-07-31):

/*
 * Sketch 16 — Omnichord
 *
 * Chord select (PCF8575, latching) + strum plate (joystick horizontal axis).
 * Sweeping the joystick across its range arpegiates the selected chord with a
 * harp-like pluck decay. Up to N_STRUM notes ring simultaneously.
 *
 * Controls:
 *   PCF keys           — select root note (latching: stays when released)
 *   Joystick L/R       — strum plate; sweep to trigger chord tones
 *   Joystick U/D       — chord type: up=mayor, down=menor, center=dom7
 *   Joystick SW        — cycle volume (8 steps, ~3 dB each)
 *   Joystick SW @ boot — force joystick recalibration
 *
 * Sound layers:
 *   Drone  — root note sostenido (fade-in 80ms) al seleccionar acorde
 *   Strum  — 8 notas del acorde con decay tipo arpa encima del drone
 *
 * Strum note layout (12 positions, low→high, ~3 octaves — igual que el OM-27):
 *   MAJOR  1  3  5  1  3  5  1  3  5  1  3  5   (C3→G6 for C root)
 *   MINOR  1 b3  5  1 b3  5  1 b3  5  1 b3  5
 *   DOM7   1  3  5 b7  1  3  5 b7  1  3  5 b7
 *
 * PCF8575 key layout:
 *   P00=E  P01=F  P02=F#  P03=G  P04=G#  P05=A  P06=A#  P07=B
 *   P10=D# P11=D  P12=C#  P13=C
 *
 * Wiring: same as sketch 15.
 *   I2S  BCK=5 DIN=6 LRCK=7
 *   SPI  SCL=9 SDA=10 RES=11 DC=12 CS=13 BLK=14
 *   I2C  SDA=4 SCL=8
 *   Joy  VRx=2 VRy=1 SW=21
 *
 * Libs: "GFX Library for Arduino" (moononournation), ESP_I2S (bundled with core).
 */

#include <Wire.h>
#include <Arduino_GFX_Library.h>
#include <ESP_I2S.h>
#include <Preferences.h>
#include <math.h>

enum ChordType { MAJOR, MINOR, DOM7 };

// Strum intervals from root (semitones), 12 positions low→high (~3 octaves)
const int STRUM[3][12] = {
  {  0,  4,  7, 12, 16, 19, 24, 28, 31, 36, 40, 43 },  // MAJOR: 4 reps de 1-3-5
  {  0,  3,  7, 12, 15, 19, 24, 27, 31, 36, 39, 43 },  // MINOR: 4 reps de 1-b3-5
  {  0,  4,  7, 10, 12, 16, 19, 22, 24, 28, 31, 34 },  // DOM7:  3 reps de 1-3-5-b7
};

// ─── display ─────────────────────────────────────────────────────────────────
#define PIN_SCLK 9
#define PIN_MOSI 10
#define PIN_RST  11
#define PIN_DC   12
#define PIN_CS   13
#define PIN_BL   14
#define BLACK RGB565_BLACK
#define RED   RGB565_RED
#define TEAL  0x05F7

Arduino_DataBus* bus = new Arduino_ESP32SPI(PIN_DC, PIN_CS, PIN_SCLK, PIN_MOSI, GFX_NOT_DEFINED);
Arduino_GFX*     gfx = new Arduino_ST7789(bus, PIN_RST, 1, true, 170, 320, 35, 0, 35, 0);

// ─── audio ───────────────────────────────────────────────────────────────────
constexpr uint32_t SAMPLE_RATE = 44100;
constexpr int      BLOCK       = 128;
constexpr int      N_STRUM     = 12;  // ~3 octaves, como la placa del Omnichord OM-27

// Harp envelope: near-instant attack, exponential decay (~1 s time constant).
// After 1 s the note is at 37%; after 3 s ≈ 5% — rings out naturally.
const float ATT_STEP    = 1.0f / (SAMPLE_RATE * 0.002f);
const float DECAY_COEFF = expf(-1.0f / (SAMPLE_RATE * 1.0f));

// Drone (root note sostenido): fade-in / fade-out suave al cambiar acorde.
const float DRONE_ATT = 1.0f / (SAMPLE_RATE * 0.08f);
const float DRONE_REL = 1.0f / (SAMPLE_RATE * 0.08f);

I2SClass i2s;

struct Voice {
  float phase     = 0;
  float inc       = 0;
  float env       = 0;
  bool  active    = false;
  bool  attacking = false;
};
Voice voices[N_STRUM];

// Voz drone: raíz sostenida mientras haya acorde seleccionado.
// Cambiar acorde reafina el drone sin resetear fase (sin click).
struct Drone {
  float phase = 0;
  float inc   = 0;
  float env   = 0;
  bool  on    = false;
} drone;

// Volume ceiling measured on the speaker+amp chain (~800 saturates the PAM8403 input).
const float VOL_LEVELS[8] = { 70, 100, 140, 200, 285, 400, 565, 800 };
int   volIdx    = 7;
float masterAmp = VOL_LEVELS[7];

float semiToFreq(int semi) { return 130.81f * powf(2.0f, semi / 12.0f); }

void triggerVoice(int pos, int semi) {
  Voice& v    = voices[pos];
  v.inc       = 2.0f * PI * semiToFreq(semi) / SAMPLE_RATE;
  if (v.env < 0.001f) v.phase = 0.0f;  // solo resetear fase si está en silencio
  v.active    = true;
  v.attacking = true;
  // env no se resetea: si la voz ya suena, el ataque sube desde donde está
}

void audioBlock() {
  int16_t buf[BLOCK * 2];
  for (int i = 0; i < BLOCK; i++) {
    float mix = 0;

    // ── drone: root note sostenido ──────────────────────────────────────────
    float droneTarget = drone.on ? 1.0f : 0.0f;
    if (drone.env < droneTarget) { drone.env += DRONE_ATT; if (drone.env > droneTarget) drone.env = droneTarget; }
    else if (drone.env > droneTarget) { drone.env -= DRONE_REL; if (drone.env < droneTarget) drone.env = droneTarget; }
    if (drone.env > 0) {
      mix += drone.env * sinf(drone.phase) * 0.5f;  // 50%: más suave que el strum
      drone.phase += drone.inc;
      if (drone.phase >= 2.0f * PI) drone.phase -= 2.0f * PI;
    }

    // ── strum: notas del acorde con decay de arpa ───────────────────────────
    for (int v = 0; v < N_STRUM; v++) {
      if (!voices[v].active) continue;
      if (voices[v].attacking) {
        voices[v].env += ATT_STEP;
        if (voices[v].env >= 1.0f) { voices[v].env = 1.0f; voices[v].attacking = false; }
      } else {
        voices[v].env *= DECAY_COEFF;
        if (voices[v].env < 0.0001f) { voices[v].active = false; continue; }
      }
      mix += voices[v].env * sinf(voices[v].phase);
      voices[v].phase += voices[v].inc;
      if (voices[v].phase >= 2.0f * PI) voices[v].phase -= 2.0f * PI;
    }

    // tanh soft clip: drone + strum completo nunca clipean.
    int16_t s = (int16_t)(masterAmp * tanhf(mix));
    buf[i * 2] = s; buf[i * 2 + 1] = s;
  }
  i2s.write((uint8_t*)buf, sizeof(buf));
}

// ─── PCF8575 ─────────────────────────────────────────────────────────────────
#define I2C_SDA  4
#define I2C_SCL  8
#define PCF_ADDR 0x20
#define DEBOUNCE_MS 8

const char* NOTE_NAME[16] = {
  "E","F","F#","G","G#","A","A#","B","D#","D","C#","C",
  nullptr,nullptr,nullptr,nullptr
};

int nameToSemi(const char* n) {
  const char* N[] = {"C","C#","D","D#","E","F","F#","G","G#","A","A#","B"};
  for (int i = 0; i < 12; i++) if (!strcmp(n, N[i])) return i;
  return -1;
}

uint16_t prevRaw = 0xFFFF, stableState = 0xFFFF;
uint32_t lastChangeMs = 0;

uint16_t readPCF() {
  Wire.requestFrom((uint8_t)PCF_ADDR, (uint8_t)2);
  if (Wire.available() < 2) return 0xFFFF;
  return Wire.read() | ((uint16_t)Wire.read() << 8);
}

// ─── joystick ────────────────────────────────────────────────────────────────
#define VRX_PIN        2
#define VRY_PIN        1
#define JOY_SW         21
#define THRESHOLD_PCT  25
#define CAL_SAMPLES    50
#define SW_DEBOUNCE_MS 50

Preferences prefs;
int centerX, centerY, threshold;

void computeThreshold() {
  int minRange = min({centerX, centerY, 4095 - centerX, 4095 - centerY});
  threshold = (minRange * THRESHOLD_PCT) / 100;
}

void runCalibration() {
  Serial.println("Calibrando — no tocar joystick...");
  delay(800);
  long sx = 0, sy = 0;
  for (int i = 0; i < CAL_SAMPLES; i++) {
    sx += analogRead(VRX_PIN); sy += analogRead(VRY_PIN); delay(10);
  }
  centerX = sx / CAL_SAMPLES; centerY = sy / CAL_SAMPLES;
  prefs.begin("joystick", false);
  prefs.putInt("centerX", centerX); prefs.putInt("centerY", centerY);
  prefs.end();
  computeThreshold();
  Serial.printf("Centro: VRx=%d VRy=%d  threshold=±%d — guardado\n", centerX, centerY, threshold);
}

void loadOrCalibrate() {
  prefs.begin("joystick", true);
  bool has = prefs.isKey("centerX");
  if (has) { centerX = prefs.getInt("centerX"); centerY = prefs.getInt("centerY"); }
  prefs.end();
  if (has) { computeThreshold(); Serial.printf("Cal cargada: VRx=%d VRy=%d threshold=±%d\n", centerX, centerY, threshold); }
  else runCalibration();
}

// ROT_90_CCW mount: dy = -(VRX - centerX).
// Physical up → VRX > centerX → dx positive → MAJOR.
ChordType joyChordType() {
  int dx = analogRead(VRX_PIN) - centerX;
  if (dx >  threshold) return MAJOR;
  if (dx < -threshold) return MINOR;
  return DOM7;
}

#define CHORD_DEBOUNCE_MS 80
ChordType debouncedChordType() {
  static ChordType stable = DOM7, pending = DOM7;
  static uint32_t pendingMs = 0;
  ChordType raw = joyChordType();
  if (raw != pending) { pending = raw; pendingMs = millis(); }
  else if (raw != stable && millis() - pendingMs >= CHORD_DEBOUNCE_MS) stable = raw;
  return stable;
}

// ─── display ─────────────────────────────────────────────────────────────────
char     shownLabel[12] = "";
int16_t  textX, textY;
uint16_t textW, textH;
uint32_t volShowUntil = 0;

void drawLabel(const char* label, uint8_t sz) {
  int16_t bx, by; uint16_t bw, bh;
  gfx->setTextSize(sz);
  gfx->getTextBounds(label, 0, 0, &bx, &by, &bw, &bh);
  int cx = (gfx->width()  - bw) / 2 - bx;
  int cy = (gfx->height() - bh) / 2 - by;
  gfx->setCursor(cx, cy);
  gfx->setTextColor(TEAL);
  gfx->print(label);
  textX = cx + bx; textY = cy + by; textW = bw; textH = bh;
}

void eraseLabel() { if (textW > 0) gfx->fillRect(textX, textY, textW, textH, BLACK); }

void updateDisplay(int rootSemi, ChordType ct) {
  if (millis() < volShowUntil) return;
  char label[12];
  if (rootSemi < 0) {
    strcpy(label, ".");
  } else {
    const char* N[]  = {"C","C#","D","D#","E","F","F#","G","G#","A","A#","B"};
    const char* suf  = (ct == MAJOR) ? "maj" : (ct == MINOR) ? "min" : "7";
    snprintf(label, sizeof(label), "%s%s", N[rootSemi], suf);
  }
  if (!strcmp(label, shownLabel)) return;
  strcpy(shownLabel, label);
  eraseLabel();
  drawLabel(label, rootSemi < 0 ? 4 : 6);
}

// ─── globals ─────────────────────────────────────────────────────────────────
int       chordRoot = -1;
ChordType chordType = DOM7;

// ─── setup ───────────────────────────────────────────────────────────────────
void setup() {
  Serial.begin(115200);
  delay(500);
  Serial.println("=== Sketch 16: Omnichord ===");

  i2s.setPins(5 /*BCK*/, 7 /*LRCK*/, 6 /*DOUT*/, -1, -1);
  if (!i2s.begin(I2S_MODE_STD, SAMPLE_RATE, I2S_DATA_BIT_WIDTH_16BIT, I2S_SLOT_MODE_STEREO)) {
    Serial.println("I2S init failed!"); while (true) delay(1000);
  }

  pinMode(PIN_BL, OUTPUT); digitalWrite(PIN_BL, HIGH);
  if (!gfx->begin()) { Serial.println("Display failed!"); while (true) delay(1000); }
  gfx->fillScreen(BLACK);

  Wire.begin(I2C_SDA, I2C_SCL);
  Wire.beginTransmission(PCF_ADDR);
  if (Wire.endTransmission() != 0) {
    gfx->setTextColor(RED); gfx->setTextSize(2);
    gfx->setCursor(8, gfx->height() / 2 - 16);
    gfx->printf("PCF8575 0x%02X", PCF_ADDR);
    gfx->setCursor(8, gfx->height() / 2 + 8);
    gfx->println("no encontrado");
    while (true) delay(1000);
  }
  stableState = prevRaw = readPCF();

  pinMode(JOY_SW, INPUT_PULLUP);
  analogReadResolution(12);
  if (digitalRead(JOY_SW) == LOW) runCalibration();
  else loadOrCalibrate();

  updateDisplay(-1, DOM7);
  Serial.println("Listo. PCF key = elige acorde (latch). Joystick L/R = strum. U/D = tipo.");
}

// ─── loop ────────────────────────────────────────────────────────────────────
void loop() {
  // ── joystick SW: cicla volumen ────────────────────────────────────────────
  static bool     prevSW = true;
  static uint32_t swMs   = 0;
  bool sw = digitalRead(JOY_SW);
  if (sw != prevSW) { swMs = millis(); prevSW = sw; }
  else if (!sw && swMs && millis() - swMs >= SW_DEBOUNCE_MS) {
    swMs = 0;
    volIdx    = (volIdx + 1) % 8;
    masterAmp = VOL_LEVELS[volIdx];
    char buf[8]; snprintf(buf, sizeof(buf), "VOL %d", volIdx + 1);
    eraseLabel(); drawLabel(buf, 5);
    volShowUntil = millis() + 800;
    shownLabel[0] = '\0';
    Serial.printf("Volumen: %d/8  (peak=%.0f)\n", volIdx + 1, masterAmp);
  }

  // ── chord type desde joystick ─────────────────────────────────────────────
  chordType = debouncedChordType();

  // ── PCF8575: detecta nueva tecla presionada (latching) ───────────────────
  uint16_t raw = readPCF();
  if (raw != prevRaw) { prevRaw = raw; lastChangeMs = millis(); }
  else if (raw != stableState && millis() - lastChangeMs >= DEBOUNCE_MS) {
    // Bits que pasaron de 1→0: tecla recién presionada (lógica activa-baja del PCF)
    uint16_t newPress = stableState & ~raw;
    stableState = raw;
    if (newPress) {
      for (int bit = 0; bit < 12; bit++) {
        if ((newPress >> bit) & 1) {
          const char* name = NOTE_NAME[bit];
          if (name) {
            int s = nameToSemi(name);
            if (s >= 0) {
              chordRoot = s;
              // Reafinar drone sin resetear fase → sin click en cambio de acorde
              drone.inc = 2.0f * PI * semiToFreq(chordRoot) / SAMPLE_RATE;
              drone.on  = true;
              Serial.printf("Acorde: %s%s\n",
                name,
                chordType == MAJOR ? "maj" : chordType == MINOR ? "min" : "7");
              break;
            }
          }
        }
      }
    }
  }

  // ── strum plate: eje Y del joystick (físico L/R en ROT_90_CCW) ───────────
  // Divide 0-4095 en N_STRUM zonas. Cruzar a una nueva zona dispara esa nota
  // con decay de arpa. Moverse en cualquier dirección produce notas.
  static int prevZone = -1;
  if (chordRoot >= 0) {
    int zone = constrain(analogRead(VRY_PIN) * N_STRUM / 4096, 0, N_STRUM - 1);
    if (prevZone >= 0 && zone != prevZone) {
      int semi = chordRoot + STRUM[chordType][zone];
      triggerVoice(zone, semi);
      Serial.printf("Strum zone %d — semi %d\n", zone, semi);
    }
    prevZone = zone;
  } else {
    prevZone = -1;
  }

  // ── display ───────────────────────────────────────────────────────────────
  updateDisplay(chordRoot, chordType);

  // ── audio ─────────────────────────────────────────────────────────────────
  audioBlock();
}

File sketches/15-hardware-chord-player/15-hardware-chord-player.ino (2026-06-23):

/*
 * Sketch 15 — Hardware chord player
 *
 * Primera integración completa sin laptop:
 *   - Teclado PCF8575 (una octava soldada) → root note
 *   - Joystick KY-023: up=mayor, down=menor, centro=nota sola
 *   - Joystick SW: cicla volumen 1→2→…→8→1 (escala logarítmica ~3 dB/paso)
 *   - Pantalla ST7789: · / C / Cmaj / Cmin; overlay "VOL 5" al cambiar volumen
 *   - Audio I2S PCM5102
 *
 * Joystick SW al boot → fuerza recalibración del centro (guardado en NVS).
 *
 * SOLDADURA PCF8575 (orden invertido respecto a docs):
 *   P00=E  P01=F  P02=F# P03=G  P04=G# P05=A  P06=A# P07=B
 *   P10=D# P11=D  P12=C# P13=C  P14–P17=libres
 *
 * Wiring (docs/hardware/wiring.md):
 *   I2S    BCK=5   DIN=6   LRCK=7
 *   SPI    SCL=9   SDA=10  RES=11  DC=12  CS=13  BLK=14
 *   I2C    SDA=4   SCL=8
 *   Joy    VRx=2   VRy=1   SW=21
 *
 * Librerías: "GFX Library for Arduino" (moononournation), ESP_I2S (incluida con core ESP32).
 */

#include <Wire.h>
#include <Arduino_GFX_Library.h>
#include <ESP_I2S.h>
#include <Preferences.h>
#include <math.h>

// ─── tipos globales (deben estar antes de los prototipos auto del IDE) ────────
enum Layer { SINGLE,
             MAJOR,
             MINOR };

// ─── colores ─────────────────────────────────────────────────────────────────
#define BLACK RGB565_BLACK
#define WHITE RGB565_WHITE
#define RED RGB565_RED
#define TEAL 0x05F7  // #00BFBD

// ─── display ─────────────────────────────────────────────────────────────────
#define PIN_SCLK 9
#define PIN_MOSI 10
#define PIN_RST 11
#define PIN_DC 12
#define PIN_CS 13
#define PIN_BL 14

Arduino_DataBus* bus = new Arduino_ESP32SPI(PIN_DC, PIN_CS, PIN_SCLK, PIN_MOSI, GFX_NOT_DEFINED);
Arduino_GFX* gfx = new Arduino_ST7789(bus, PIN_RST, 1, true, 170, 320, 35, 0, 35, 0);
// rotation=1 → 90° CW → landscape 320×170

// ─── audio ───────────────────────────────────────────────────────────────────
#define PIN_BCLK 5
#define PIN_DOUT 6
#define PIN_LRCK 7

constexpr uint32_t SAMPLE_RATE = 44100;
constexpr int BLOCK = 128;

// Envolventes:
//   ATT  4 ms  — ataque al inicio de nota
//   REL  20 ms — release natural al soltar tecla
//   XFADE 2 ms — micro-fadeout antes de cambiar parámetros de audio;
//                2 ms es imperceptible como silencio pero evita todo click
const float ATT_STEP = 1.0f / (SAMPLE_RATE * 0.004f);
const float REL_STEP = 1.0f / (SAMPLE_RATE * 0.020f);
const float XFADE_STEP = 1.0f / (SAMPLE_RATE * 0.002f);

I2SClass i2s;

float phs[3] = { 0, 0, 0 };
float incs[3] = { 0, 0, 0 };
int numVoices = 1;
float voiceAmp = 0;
float env = 0;
bool noteOn = false;

// Crossfade: cuando hay que cambiar frecuencias/voces sin click,
// se hace un micro-fadeout a 0 y se dispara el retrigger al llegar.
bool retriggering = false;
int pendingSemi = -1;
Layer pendingLayer = SINGLE;

float semiToFreq(int semi) {
  return 261.63f * powf(2.0f, semi / 12.0f);
}

// ─── volumen (escala logarítmica ~3 dB por paso, factor ≈ √2) ────────────────
//
// Techo medido en el speaker interno: ~800 (>800 distorsiona).
const float VOL_LEVELS[8] = { 70, 100, 140, 200, 285, 400, 565, 800 };
int volIdx = 7;
float peakVolume = VOL_LEVELS[7];

// ─── PCF8575 ─────────────────────────────────────────────────────────────────
#define I2C_SDA 4
#define I2C_SCL 8
#define PCF_ADDR 0x20
#define DEBOUNCE_MS 8

const char* NOTE_NAME[16] = {
  "E",
  "F",
  "F#",
  "G",
  "G#",
  "A",
  "A#",
  "B",
  "D#",
  "D",
  "C#",
  "C",
  nullptr,
  nullptr,
  nullptr,
  nullptr,
};

int nameToSemi(const char* name) {
  const char* N[] = { "C", "C#", "D", "D#", "E", "F", "F#", "G", "G#", "A", "A#", "B" };
  for (int i = 0; i < 12; i++)
    if (strcmp(name, N[i]) == 0) return i;
  return -1;
}

uint16_t prevRaw = 0xFFFF;
uint16_t stableState = 0xFFFF;
uint32_t lastChangeMs = 0;

uint16_t readPCF() {
  Wire.requestFrom((uint8_t)PCF_ADDR, (uint8_t)2);
  if (Wire.available() < 2) return 0xFFFF;
  uint8_t lo = Wire.read();
  uint8_t hi = Wire.read();
  return (uint16_t)lo | ((uint16_t)hi << 8);
}

const char* firstPressed(uint16_t state) {
  for (int bit = 0; bit < 12; bit++)
    if (!(state & (1u << bit))) return NOTE_NAME[bit];
  return nullptr;
}

// ─── joystick ────────────────────────────────────────────────────────────────
#define VRX_PIN 2
#define VRY_PIN 1
#define JOY_SW 21
#define THRESHOLD_PCT 25
#define CAL_SAMPLES 50
#define SW_DEBOUNCE_MS 50

enum Mount { ROT_0,
             ROT_90_CW,
             ROT_180,
             ROT_90_CCW };
#define JOY_MOUNT ROT_90_CCW  // verificado en placa de test (sketch 12)

Preferences prefs;
int centerX, centerY, threshold;

void applyMount(int rvx, int rvy, float& dx, float& dy) {
  switch (JOY_MOUNT) {
    case ROT_0:
      dx = -rvx;
      dy = -rvy;
      break;
    case ROT_90_CW:
      dx = -rvy;
      dy = rvx;
      break;
    case ROT_180:
      dx = rvx;
      dy = rvy;
      break;
    case ROT_90_CCW:
      dx = rvy;
      dy = -rvx;
      break;
  }
}

void computeThreshold() {
  int minRange = min({ centerX, centerY, 4095 - centerX, 4095 - centerY });
  threshold = (minRange * THRESHOLD_PCT) / 100;
}

void runCalibration() {
  Serial.println("Calibrando joystick — no tocar...");
  delay(1000);
  long sumX = 0, sumY = 0;
  for (int i = 0; i < CAL_SAMPLES; i++) {
    sumX += analogRead(VRX_PIN);
    sumY += analogRead(VRY_PIN);
    delay(10);
  }
  centerX = sumX / CAL_SAMPLES;
  centerY = sumY / CAL_SAMPLES;
  prefs.begin("joystick", false);
  prefs.putInt("centerX", centerX);
  prefs.putInt("centerY", centerY);
  prefs.end();
  computeThreshold();
  Serial.printf("Centro: VRx=%d VRy=%d  threshold=±%d — guardado\n", centerX, centerY, threshold);
}

void loadOrCalibrate() {
  prefs.begin("joystick", true);
  bool hasCal = prefs.isKey("centerX");
  if (hasCal) {
    centerX = prefs.getInt("centerX");
    centerY = prefs.getInt("centerY");
  }
  prefs.end();
  if (hasCal) {
    computeThreshold();
    Serial.printf("Calibración cargada: VRx=%d VRy=%d  threshold=±%d\n", centerX, centerY, threshold);
  } else {
    runCalibration();
  }
}

// Si UP/DOWN salen invertidos en hardware: swapear los signos de dy.
Layer joyLayer() {
  float dx, dy;
  applyMount(analogRead(VRX_PIN) - centerX, analogRead(VRY_PIN) - centerY, dx, dy);
  if (dy < -threshold) return MAJOR;
  if (dy > threshold) return MINOR;
  return SINGLE;
}

// Al mover el joy de UP a DOWN pasa por CENTER ~20-40 ms. Sin debounce eso
// dispara SINGLE brevemente y se oye como ruido entre acordes.
#define LAYER_DEBOUNCE_MS 80

Layer debouncedJoyLayer() {
  static Layer stable = SINGLE;
  static Layer pending = SINGLE;
  static uint32_t pendingMs = 0;

  Layer raw = joyLayer();
  if (raw != pending) {
    pending = raw;
    pendingMs = millis();
  } else if (raw != stable && millis() - pendingMs >= LAYER_DEBOUNCE_MS) {
    stable = raw;
  }
  return stable;
}

// ─── audio ───────────────────────────────────────────────────────────────────
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

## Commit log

2026-05-31 Restructure docs: brief + hardware + plan + glossary
    Consolidate the two duplicate ChatGPT/Claude summaries into a focused doc set:
    - brief.md: WHY/WHAT only (pitch, vision, inspirations, principles, non-goals,
    success signals); reimagined-Stylophone thesis, DIY/open-source identity
    - hardware.md: component decisions, Mermaid diagrams, PCM5102+PAM8403 audio path
    (marked draft, pending bench tests)
    - plan.md: checklist-driven build plan by phase (limits → hardware → software/base
    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
2026-05-31 Add hardware/wiring/dev docs, design concepts, and ESP32-S3 test sketches
    Docs:
    - New module docs (esp32-s3-devkit, pcm5102, st7789), wiring.md, development.md
    - design.md: AI-generated concept render gallery (prompt + nano banana/ChatGPT)
    - brief: link product images/pages in Inspirations; pointer to design.md
    - plan: explicit Phase 2 test sequence + re-evaluation checkpoint
    - README: link design.md in docs index
    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
2026-06-01 Add note/chord/display sketches; document PCM5102 + ST7789 wiring
    Firmware (src/):
    - 04-audio-notes, 04-audio-notes-ble: serial → notes over I2S (BLE variant untested)
    - 05-audio-pitch-wave: LFO pitch glide
    - 06-display-hello: ST7789 first light (Arduino_GFX) — verified
    - 07-chord-player: hold-to-sound single/maj/min layers + landscape UI — verified
    - DAC pins finalized at GPIO5/6/7; display at GPIO9-14 (screen header order)
    - pcm5102.md: SCK/jumper explainer + inverted H/L label warning
    - wiring.md: DAC + ST7789 tables, left-header layout, free-pin notes
    - development.md: sketch list, serial/BLE input notes, Arduino_GFX library
    - README: screen serial-terminal tip
    - plan.md: Ph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
    [03-PCM5102A-test.ino, 04-audio-notes-ble.ino, 04-audio-notes.ino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]
2026-06-03 Fix broken link to src/10-synth-voice in synthesis.md
    [03-PCM5102A-test.ino, 04-audio-notes-ble.ino, 04-audio-notes.ino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]
2026-06-03 Reorganize project structure: firmware/, app/, docs cleanup
    - Move src/sketches → firmware/, src/tools → app/
    - Add .gitignore (macOS, Arduino build cache, Node/Vite, editors)
    - Update all doc references to new paths
    - Mark 10-audio-looper as next test (sketch removed for now)
2026-06-03 Add 10-audio-looper sketch and looper-bridge web app
    Step sequencer with live recording and step-entry editing:
    - 4 layers × up to 32 steps (4/8/12/16/32 selectable at runtime)
    - Live mode: notes captured into pattern in real time while playing + recording
    - Entry mode: ←→ navigate steps, ↑↓ switch layer, piano keys toggle notes
    - Per-layer volume (A{l}{0-9}), precomputed per-voice mix in audioBlock
    - Free improvisation: held keys sustain across step boundaries when not recording
    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
2026-06-04 Fix stuck notes on pattern clear; add UX guards and Delete shortcut
    Firmware:
    - stopPlay() now force-mutes all voices directly instead of relying on
    pattern state (which may be 0 after a clear, leaving orphaned voices)
    - gateOrphanedNotes() gates off any voice no longer in pattern or heldKeys;
    called after X, Y, and Z commands so stuck notes stop immediately
    Bridge:
    - All clear buttons disabled while playing (CSS + JS) as a belt-and-suspenders
    guard against the stuck-note scenario
    - Delete / Backspace mapped to clear the current entry step (stopped only)
    [10-audio-looper.ino]
2026-06-04 Document synthesis research, define architecture, drop drum sketch
    - Remove firmware/11-drum-machine: linear decay and 1-pole HP filter
    produced poor results; root causes documented for when we return
    - docs/theory/drums.md: rewritten as research doc — what sketch 11 got
    right/wrong, how TR-808/909/606/PO-33/Stylophone Beat actually work,
    reference machine list with synthesis notes per machine
    - docs/theory/digital-synths.md: new — synthesis paradigms overview,
    Serum 2 breakdown (oscillator types, modulation matrix), DigitsVst
    phase distortion, Hichord manual findings (12 oscillators, diatonic
    7-button layout, joystick chord extensions), YouTube learning list,
    open-source C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
2026-06-09 Restructure docs: rename theory→research, drop glossary, clean stale content
    - Rename docs/theory/ → docs/research/ (synthesis, drums, music-theory, digital-synths)
    - Delete docs/glossary.md (not worth maintaining)
    - Strip AI prompt text from docs/design.md; keep concept renders
    - Fix all cross-references to reflect new paths
    - Update CLAUDE.md: mark drum decision ✅, add research blockers before Phase 3
    - Update architecture.md: add research-blocked status at top, fix stale content
    - Update plan.md: add research blocker note at Checkpoint
    - Update development.md, hardware/README.md, research/synthesis.md: remove stale notes
2026-06-21 Document power subsystem + update hardware BOM/sourcing
    Single combined USB-C 2.0 port (VBUS -> charge/discharge module,
    D+/D- -> ESP32 native USB for serial + USB-MIDI). One IP5306-class
    charge + 5V boost + power-path module with KEY pin as power button;
    no separate boost/charger/switch. Refresh the on-hand/sourcing and
    tools tables with current purchase status (AliExpress + local AR).
2026-06-21 Add min7/maj7 momentary chord layers to note-gate sketch + bridge
    Extend the monophonic chord engine from triads to seventh chords: grow
    the per-key oscillator arrays 3->4, add MIN7/MAJ7 layers (root,3rd,5th
    +10/+11), wire serial chars '{' '}' and the bridge's Left/Right arrows.
    [09-audio-notes-gate.ino]
2026-06-21 Sync docs to decided hardware: PCF8575 keyboard, key design, enclosure
    Mark input method + key design as decided across CLAUDE.md, plan, and
    explorations. Document the 25-key 2x PCF8575 wiring, EC11/SK6812/joystick
    pin tables, the 40mm speaker upgrade, and add the PCF8575/SK6812 module
    docs, key-design + design-system explorations, and interior layout SVG.
2026-06-22 Add KY-023 joystick test sketch + orientation handling
    Sketch 12: read both axes + button, NVS auto-calibration, and a single
    JOY_MOUNT knob that maps centered deltas into a world frame (resolves
    axis swap + polarity together). Verified ROT_90_CCW on the test board;
    other orientations derived as a consistent rotation, flagged unverified.
    Docs: new modules/ky023.md, wiring + README updated to verified/wired,
    plan.md peripheral check + sketch table. All text in English.
    [12-ky023-joystick-test.ino]
2026-06-23 Add PCF8575 + display + hardware chord player sketches; update docs
    Sketches 13–15: PCF8575 keyboard test, keyboard→display, and full
    hardware integration (PCF8575 + KY-023 + ST7789 + I2S). Sketch 15
    includes major/minor chords via joystick, 8-level logarithmic volume,
    click-free crossfade on note/layer changes, and layer debounce to
    avoid ghost single notes when flicking the joystick UP→DOWN.
    Also adds Panasonic R1088 and Roland P-6 to brief.md inspirations,
    and adds Milestone v0.2 (consolidated protoboard + test menu UI) plus
    sketches 13–15 to the exploration log in plan.md.
    [13-pcf8575-keyboard-test.ino, 14-pcf8575-display.ino, 15-hardware-chord-player.ino]
2026-07-31 Add sketch 16 (omnichord) + expand brief inspirations
    Chord select via PCF8575 (latching) + joystick strum plate with harp-like
    pluck decay. Brief gains LOOPA, minichord, CHOMPI, FM-1, 303/606 acid-line
    references, isomorphic keyboard videos, and two research flags.
2026-07-31 Docs: OP-1 flat-cap pivot (V1) + KS-33 module doc + toolchain/proto explorations
    - 0002/0003 revised: flat rectangular caps directly on switches, lever bridge
    deferred; keyboard depth 72→~35mm, cap depths back on the 4mm grid
    - New: gateron-ks-33.md (vernier-measured Silent specs, STEP-sliced stem dims),
    0004 CAD toolchain decision (OpenSCAD + KiCad), 0005 one-octave proto module
    - plan.md: toolchain/layout/measurement checkboxes + test-fit kit PASSED
    (PLA/PETG, 0.2 & 0.4 nozzles, 3 print services)
    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
2026-08-01 feat(3d): plate.scad first pass — v1.0 test-batch scope
    [plate.scad]
2026-08-02 feat(3d): directional key_cap family, assembly, pitch 18.8 + STLs
    - key_cap.scad FINAL for batch 2: OEM-style directional profile (deep
    bevel 2.4 on the touch side, 1.2 rest; G# all-light), 0.4mm design
    grid, per-arm cross bore from official stem cotas 1.23/1.10 (1.28 was
    a misread) -> slots 1.28 = print-validated fit; bore 4.1, R0.3, flare
    0.2, bottom chamfers (skirt + post)
    - plate.scad: pitch 18.8 (gap 0.8), margin 1.6, prad 3.2 -> 134x58.4
    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
    [assembly.scad, key_cap-natural.stl, key_cap-sharp1.stl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]
2026-08-02 feat(3d): PCF8575 vertical mount in D#-F# bay + derived back tab
    [plate.scad]
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2026-08-03 feat(3d): as-built routing + module restructure (keyboard/, vendor/)
    Final wire routing lives in plate.scad (routing source of truth; wiring-plan.svg re-synced to as-built). hardware/3d reorganized one folder per module family; vendor/ carries third-party meshes with 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
    [assembly.scad, key_cap-natural.stl, key_cap-sharp1.stl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]
2026-08-03 docs: sync plan, refs and cad skill to the 3d restructure
    All hardware/3d links retargeted to keyboard/; module docs point at the committed vendor meshes; plan logs the cleanup session (routing, restructure, ghost decision, param freeze, SVG re-sync); hole_chamfer relief claim corrected to the built 45deg x 0.15.
